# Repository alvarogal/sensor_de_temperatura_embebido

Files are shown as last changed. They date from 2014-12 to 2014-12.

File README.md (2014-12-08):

sensor_de_temperatura_embebido
==============================

Este proyecto integra el uso de un termopar con un sistema embebido usando linux, de tal forma que el usuario se pueda leer con un dipositivo conectado de forma inalámbrica al sistema, la temperatura medida en el termopar. Aquí se encuentran los recursos utilizados para lograr este objetivo.

Equipo de desarrollo.

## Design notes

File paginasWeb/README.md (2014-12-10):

Los archivos usados al final son:
server.js
index.html
guia1.html (grafica de la temperatura)
guias.html
tuto.html
inicio.html
medir.html (pagina que tienen el link para iniciar la grafica)
readTermo  (programa que usa server.js para leer el valor de temperatura en ese instante)
error (archivo donde se guarda un entero que lee con server.js e informa al usuario cuando el termopar se desconecta)
stylesheets (carpeta con los .css para el estilo de las paginas)
images (carpeta con las imagnes)

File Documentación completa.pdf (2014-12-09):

# SISTEMAS EMBEBIDOS DESARROLLO DEL PROYECTO

### Sebastián Corzo Gómez – scorzog@unal.edu.co José Logreira Ávila – jalogreiraa@unal.edu.co

## Stamp-Mini

Se eligió utilizar la tarjeta mini-stamp, diseñada por el ingeniero Camargo, que es una versión compacta de una tarjeta con mayores prestaciones. El diseño del PCB fue hecho en Kicad, y la lista de materiales fue elaborada por Camargo, incluyendo los códigos de las partes en Digikey. Los materiales fueron pedidos por Digikey.com, y las PCBs fueron elaboradas en PCBcart en China.

### Ensamble de la tarjeta:

Materiales y herramientas necesarias para el ensamble:

- Estación de soldadura: Pinzas de soldadura, Cautín con punta fina.
- Líquido Flux, para limpieza de superficies
- Alcohol isopropílico

Se inicia soldando los componentes pasivos, como los condensadores y las resistencias. Se limpia la PCB con alcohol isopropílico usando un cepillo. Una vez seca se deben estañar todos los pads de los componentes a soldar. Los circuitos integrados no se les debe aplicar mucho estaño a los pads, puesto que al poner el chip, no sería fácil posicionarlo pues los pads estarían abultados.

Se aplica un poco de Flux en los pads del componente a soldar. Con las pinzas para soldadura se coge el componente a soldar por las puntas metalizadas, y se ubica encima de los pads donde este debe ser soldado. El calor derretirá el estaño ya aplicado en los pads, y también quedará adherido a los extremos metalizados del componente. Cuando el componente haya entrado en contacto con el estaño de los pads en sus dos extremos, la pinza se puede retirar, y se verifica si el componente quedó fijado firmemente, o si está levantado. Usando las mismas pinzas de soldadura se pueden realizar reacomodaciones del componente. Es importante siempre usar Flux cuando se solde cada componente, pues limpia la superficie y ayuda a una mejor transferencia de calor.

Al soldar los chips (procesadores y memorias), se debe primero posicionar el IC tal que todas las patas queden alineadas con las pistas a las que van soldadas. Manteniendo fijo el chip, con el cautín de punta fina, se solda solo la pata de un extremo, y la pata del extremo opuesto, pasando ligeramente el cautín sobre la pata a soldar. Solo con estas dos patas soldadas, se verifica que todas las demás patas del IC continúen alineadas con las pistas del PCB. Si no lo están, pasando repetidamente el cautín por las patas soldadas se puede derretir el estaño y realinear el chip completo. Estando satisfechos con la alineación, se procede a soldar el resto de patas del IC, pasando rápidamente el cautín por cada pata individualmente, procurando que no haya estaño aderido a la punta del cautín.

Finalmente, se soldan las regletas laterales de la tarjeta. Cuando la tarjeta esté lista, se lava completamente con alcohol isopropílico, cepillandola con un cepillo de dientes. Se puede verificar con un multímetro que no haya continuidad de las lineas de alimentación y tierra, ni entre los pines de los chips. Esto teniendo en cuenta el esquemático del PCB.

### Comunicación con el exterior:

La tarjeta posee múltiples pines de comunicación. Los que se han de usar para la programación y la interfaz con el usuario son:

- USB DP (+) y DM(-): para realizar carga de programas pequeños a la memoria interna del procesador y probar el funcionamiento de la tarjeta.
- Serial Port Rx y Tx: Para la interacción entre el usuario y la tarjeta usando Minicom.

Para la comunicación usando los terminales USB, se usa un cable USB a miniUSB, al cual se le recorta el extremo del terminal miniUSB; a los 4 cables (+5V, GND, DP, DM), se les adapta una regleta hembra tal que se puedan conectar de a pares a la regleta macho de la tarjeta (+5V y GND juntos, y DP y DM juntos). Los terminales +5V y GND energizan toda la tarjeta.

Para la comunicación serial se requiere un IC que sirva de interfaz entre el protocolo USB y serial, pero usando niveles lógicos de 0V y 3.3V que son los que usa el procesador. Esta característica en el mercado se conoce como “USB to serial - TTL compatible”. En el mercado se consigue un pequeño PCB que tiene montado el conector USB, el IC PL2303hx, y 5 pines de salida, que son Rx, Tx, GND, +5V, +3.3V. Para comunicar la tarjeta con esta interfaz se usa un cable ribbon de 5 hilos, y en ambos extremos se le adapta regletas hembra para poderse conectar a los pines Tx Rx del PL2303hx, y a los pines Rx y Tx de la tarjeta.

### Prueba de funcionamiento:

Las instrucciones a continuación fueron entregadas por el Ing. Camargo para la prueba de la Ministamp. Se requiere de una memoria micro SD de 2GB o más, y el cable USB previamente fabricado. Previamente se requiere también instalar libusb, que se encuentra disponible en el gestor de software de Ubuntu, aunque la opción que nos funcionó correctamente fue descargar e instalar manualmente libusb desde el sitio oficial http://www.libusb.org/.

Descarga de Lua:
$ wget http://www.lua.org/ftp/lua-5.2.2.tar.gz
$ tar zxvf lua-5.2.2.tar.gz
$ cd lua-5.2.2
$ make linux
$ sudo make install
$ sudo cp /usr/local/lib/liblua.a /usr/lib/

Lua es un lenguaje compacto, interpretado, ligero y sencillo, y es uno de los que soporta el i.MX .

Crear las particiones necesarias en la SD, formatear la memoria SD y grabar el bootloader y el sistema de archivos:

Se necesitan dos particiones en la SD, la primera almacenará el boot-loader y la imágen del kernel; la segunda almacenará el sistema de archivos. Para los siguientes comandos se asume que la tarjeta es detectada como /dev/sdb (para conocer el dispositivo asignado a la tarjeta por Linux se debe insertar la tarjeta y ejecutar el comando $ dmesg)

Desmontar la partición y ejecutar fdisk:
$ sudo umount /dev/sdb*
$ sudo fdisk /dev/sdb

Borrar las particiones existentes: Dentro de fdisk se debe escribir "d" (delete a partition)

Command (m for help): d
Partition number (1-4):

En el campo "Partition number" se debe escribir el número de la partición a ser eliminada, el proceso se debe repetir hasta borrar todas las particiones existentes.

Crear una partición de 200MB : Dentro de fdisk se debe escribir "n" (add a new partition) . Seleccionar partición primaria: Escribir "p"

Command (m for help): n
Partition type:
p primary (0 primary, 0 extended, 4 free) e extended
Select (default p): p
Partition number (1-4, default 1): 1

Fijar el comienzo de la partición. Al mensaje:

First sector (2048-7626751, default 2048):

Se debe oprimir la tecla enter para asignar el valor por defecto. A lo que la aplicación responde:

Using default value 2048

Fijar el final de la partición. Al mensaje:
Last sector, +sectors or +size{K,M,G} (2048-7626751, default 7626751):

Ingresar +200M A lo que el sistema responde:

Partition 1 of type Linux and of size 200 MiB is set

Crear la segunda partición en el espacio sobrante en la SD : Dentro de fdisk se debe escribir "n" (add a new partition) . Seleccionar partición primaria: Escribir "p" . Asignar el número de la partición a "2"

Command (m for help): n
Partition type:
p primary (1 primary, 0 extended, 3 free) e extended
Select (default p): p
Partition number (1-4, default 2): 2

Fijar el comienzo de la partición: Dejar el valor por defecto Fijar el final de la partición: Dejar el valor por defecto

First sector (411648-7626751, default 411648):
Using default value 411648
Last sector, +sectors or +size{K,M,G} (411648-7626751, default 7626751):
Using default value 7626751
Partition 2 of type Linux and of size 3.5 GiB is set

Cambiar el tipo de la partición 1 a OnTrack DM6 (53) : Dentro de fdisk escribir "t" (change a partition's system id) . Escribir "53" . Este es el formato de partición que Freescale diseñó para el i.MX.

Command (m for help): t
Partition number (1-4): 1
Hex code (type L to list codes): 53
Changed system type of partition 1 to 53 (OnTrack DM6 Aux3)

Cambiar el tipo de la partición 2 a Linux (83) : Dentro de fdisk escribir "t" (change a partition's system id) . Escribir "83"

Command (m for help): t
Partition number (1-4): 2
Hex code (type L to list codes): 83

Al finalizar se debe tener la siguiente tabla de particiones, la cual se obtiene al ejecutar el comando "p" (print the partition table);

Device Boot | Start | End | Blocks Id System
/dev/sdb1 | 2048 | 411647 | 204800 53 OnTrack DM6 Aux3
/dev/sdb2 | 411648 | 7626751 | 3607552 83 Linux

Una vez finalizada la creación de las particiones se deben guardar los cambios en la tabla de particiones de la SD, para esto debe ejecutar el comando "w" (write table to disk and exit)

Command (m for help): w
The partition table has been altered!

Calling ioctl() to re-read partition table. Syncing disks.

Formatear la segunda partición como ext3:

$ sudo mkfs.ext3 /dev/sdb2

Almacenar el boot-loader y la imágen del kernel a la SD: El bootloader y la imágen se encuentran en la carpeta Factory_Test/basic/files.

$ sudo dd if=sd_mmc_bootstream.raw of=/dev/sdb1
$ sudo umount /dev/sdb*

Grabar el sistema de archivos a la segunda partición: El .tar.bz2 se encuentra en la carpeta files.

$ sudo tar -jxvf buildroot_fs.tar.bz2 -C /media/disk/

Cambiar los OTPs para permitir la inicialización por la SD (se realiza solo una vez): Por defecto el iMX233 no permite inicializar desde la SD, para habilitar esta opción es necesario cambiar el valor del registro interno OCOTP.ROM0, esto se realiza una única vez.

Compilación de las herramientas necesarias para la modificación del registro OCOTP.ROM0 Descomprimir y compilar el código fuente: en la carpeta basic:

$ cd Factory_Test
$ ./build

Al finalizar el proceso sin errores deben existir dos nuevos ejecutables en /usr/local/bin: hwstub_shell sbloader

Cargar la aplicación blink: (alimentar y conectar el cable USB a la stamp): Para asegurarse que la tarjeta es reconocida al conectarla, se ejecuta el comando $ lsusb.

load_blink

El LED D3 (esquina superior derecha) parpadeará, lo que indica que la placa se encuentra bien soldada y está funcionando de forma adecuada .

Para programar los registros que permiten arrancar desde la SD debe ejecutar el script

burn_OTP

Y con esto ya puede arrancar con la SD que creó anteriormente.

Se conecta el dispositivo USB a serial, usando el cable ribbon, a los pines Rx y Tx de la tarjeta, alimentandola también con los pines de +5V y GND. Se abre una consola de Minicom donde abre las opciones de configuración del puerto:

$ sudo minicom -s

En la pestaña serial port setup se configura el puerto del dispositivo a usar (en nuestro caso: /dev/ttyUSB0), se establece la rata de baudios y los bits de paridad y de inicio como 115200 8N1. No se habilita el flujo de control de hardware ni de software. Se guardan los cambios y se entra en la consola del puerto. Apenas se energiza la tarjeta, en la consola se muestran los comandos iniciales del boot del procesador, y comienza la carga del sistema operativo. Cuando el sistema termina de cargar, el SoC debe pedir el login: root, y el password: root. Al llegar a este paso, todo el sistema cargó correctamente y ya se puede empezar a hacer uso del OS cargado en la tarjeta.

NOTA: El bootloader, el kernel y el sistema de archivos cargados hasta ahora son todos imágenes precompiladas por el Ing. Camargo, que se usan únicamente para probar el funcionamiento inicial de la tarjeta. A continuación se describe cómo compilar desde ceros la imagen del kernel y el sistema de archivos.

### Compilando la imagen del Sistema de archivos

Parte del material del curso es el archivo comprimido buildroot-2013.08.1. Este contiene un programa llamado Buildroot. Es una herramienta que simplifica y automatiza el proceso de creación de un sistema Linux completo para un sistema embebido, usando la compilación cruzada. Para construir el sistema Linux, Buildroot puede generar un set de herramientas de crosscompilación, un sistema de archivos raíz, una imágen del núcleo Linux y un gestor de arranque (bootloader) para la mini-stamp.

Buildroot se puede usar para cualquiera de las tareas anteriormente descritas, en cualquier combinación que se quiera. Soporta múltiples procesadores y viene con múltiples configuraciones preformadas para tarjetas específicas.

En el directorio raíz buildroot-2013.08.1 se encuentra un Makefile con el cual se realizan todas las acciones necesarias a usar con Buildroot. Al ejecutar:

$ make menuconfig

Se abre una interfaz gráfica en donde se encuentran jerarquizadas todas las opciones de configuración de Buildroot: se puede elegir que clase de sistema de archivos crear, que versión de kernel, que opciones de boot, que paquetes y aplicaciones se desean incluir en el sistema de archivos, que herramientas de desarrollo se desean incluir, etc. Por defecto ya viene un archivo de configuración cargado con las opciones básicas para realizar aplicaciones sencillas con la ministamp. Este archivo se llama .config y se encuentra en el directorio raíz de Buildroot. Si se realizan cambios en la interfaz de configuración, y se guardan los cambios, este archivo se modifica.

Por ahora, la configuración que viene por defecto es casi suficiente para nuestro propósito por lo que solo es necesario modificar un par de parámetros: en menú System Configuratio, se modifica el System banner: “Welcome to buildroot: Sebastián y Jose”, y el parámetro Port to run a getty (logging prompt) on: “ttyAM0”, que es el puerto serial del SoC a través del cual se va a transmitir a Minicom la consola de Buildroot.

Correr Buildroot con la configuración por defecto creará un sistema de archivos básico y toda la cadena de herramientas del cross-compilador. No creará un bootloader, ni una imágen del kernel

Linux.

Para correr Buildroot, nos ubicamos en el directorio raíz de buildroot, y se ejecuta $ make. Comienza un proceso de descarga de internet de todos los paquetes necesarios, que los va guardando como comprimidos en la carpeta buildroot-2013.08.1/dl. Luego empieza a compilarlos usando el cross-compilador seleccionado para el i.MX. Este es un proceso que puede tardar al rededor de 2 horas.

Al llegar a la compilación del paquete llamado openocd, muestra un error por un Warning, y no permite continuar con la compilación. Este error es debido a que en el Makefile de este paquete, los warnings están definidos para que los tome como errores. Por esto, algunos warnings que no afectan el funcionamiento del sistema son tomados como errores. Para solucionarlo, nos dirigimos hasta donde se encuentra el Makefile en ejecución, que se encuentra en la ruta: buildroot-2013.08.1/output/build/openocd-0.7.0/src/target, y se abre el Makefile con gedit. Se busca el flag -Werror, que está escrito dos veces en todo el archivo. Se borra y se guardan los cambios.

Nuevamente se regresa al directorio raíz de buildroot y se vuelve a correr $ make. Esta vez la compilación continúa sin errores hasta que acaba todas las tareas. El resultado final es que en el directorio buildroot-2013.08.1/output/images se encuentra la imágen del sistema de archivos creada, comprimida. Teniendo esta imágen ya creada, se descomprime en la segunda partición de la SD.

### Compilando la imagen del Kernel de Linux:

Parte del material de clase son dos archivos comprimidos llamados:

- linux-2.6.35.3.tar.bz2: Contiene todo el código fuente del núcleo Linux. Además, también contiene un programa con una interfaz gráfica basada en la librería curses (la misma usada para el programa buildroot) donde se encuentran múltiples opciones de configuración del kernel.
- Imx-bootlets-src-10.05.02.tar.bz2: Son herrmientas para copiar la imagen de linux (creada en la carpeta anterior) a la SD, junto con un conjunto de configuraciones de registros internos del procesador i.MX, necesarios para que este pueda inicializar reguladores de tensión, memorias externas y buses de comunicación.

Estos se descomprimen en un mismo directorio.

### Modificación de la variable PATH:

Un primer paso en modificar la variable de entorno PATH, añadiendole la ruta donde se encuentra el cross-compilador que fue creado usando buildroot. Esto se realiza modificando el archivo .bashrc que se encuentra en el folder del usuario (/home/jose en nuestro caso):

### $ cd /home/jose $ gedit .bashrc

Al final del archivo se añade la linea de comando:

export PATH=$PATH:/home/jose/Documents/EMBEDDED_SYSTEMS/buildroot-2013.08.1/output/host/ usr/bin/

Esto modifica la variable PATH añadiendole una nueva ruta de búsqueda de ejecutables. La ruta especificada es donde se encuentra el cross-compilador.

### Creación de la imagen de Linux:

Dentro de la carpeta linux-2.6.35.3 hay un Makefile que será usado para compilar todo el núcleo Linux, usando el cross-compilador generado en la carpeta buildroot-2013.08.1.

Para editar las opciones de configuración del kernel, se abre la interfaz gráfica parecida a la existente en buildroot-2013.08.1, la cual permite listar y seleccionar las múltiples configuraciones. Para esto se ejecuta en el directorio raíz de linux-2.6.35.3:

$ make ARCH=arm CROSS_COMPILE=arm-linux- menuconfig

donde ARCH=arm especifica que se va a compilar para la arquitectura ARM, y CROSS_COMPILE = arm-linux- especifica el cross-compilador que se va a usar. Finalmente, se especifica la directríz a ejecutar: menuconfig.

Al ejecutar este comando, se presenta un error de un enlace roto a un archivo. En la carpeta buildroot-2013.08.1/output/host/usr/bin/ existen múltiples archivos que son enlaces a otros archivos ubicados en esa misma carpeta. El enlace roto se presenta en este archivo: arm-linuxld.real, que apunta a arm-buildroot-linux-uclibcgnueabi-ld.real. Este problema se soluciona creando manualmente el enlace, así:

$ ln -s arm-buildroot-linux-uclibcgnueabi-ld.real arm-linux-ld.real

donde la opción “-s” crea un enlace simbólico entre ambos archivos.

Al volver a correr el comando make (…) se abre la ventana de la interfaz gráfica que muestra las opciones de configuración del kernel.

Al correr el siguiente comando, se genera la imágen del kernel de linux:

$ make ARCH=arm CROSS_COMPILE=arm-linux-

Esta ejecución se demora de 10 a 15 minutos. La imagen final del Kernel Linux la crea en la carpeta linux-2.6.35.3/arch/arm/boot, y tiene como nombre zImage. Éste es el Sistema Operativo propiamente dicho, el cual se debe grabar en la primera partición de la SD, usando las herramientas ubicadas en la carpeta Imx-bootlets-src-10.05.02.

### Pasar la imagen del Kernel a la SD:

La carpeta Imx-bootlets-src-10.05.02 con la configuración necesaria para el I.MX es proporcionada por Freescale, y contiene la configuración de boot del procesador, donde inicializa los buses de comunicación con las memorias, los reguladores internos de voltaje y registros de configuración.

En el directorio raíz de la carpeta hay un Makefile, el cual se debe correr para pasar la imagen del Kernel a la tarjeta SD. Se debe asegurar que la tarjeta micro SD sea leída como “sdb”, puesto que así está definida la ruta en el Makefile. Si se usa un adaptador microSD a USB, el sistema leerá la SD como un dispositivo de nombre “p”, por lo que se debe modificar esta ruta a /dev/p1.

Para correr el Makefile, se ejecuta el comando siguiente:

$ make ARCH=mx23 CROSS_COMPILE=arm-linux-

Este comando arroja error en la compilación pues no encuentra el comando “elftosb2”, el cual es el programa encargado de convertir el formato de archivos elf (Executable & Linkable File) al formato sb, que es el que reconoce el procesador.

Este programa nos lo envió el Ing. Camargo. Es un archivo binario que se debe copiar en la carpeta /usr/bin, y se le deben cambiar los permisos de ejecución:

$ sudo chmod +x /usr/bin/elftosb2

Así, al volver a correr el Makefile, este realiza todos los procesos sin errores, y la imágen del kernel ya queda pasada sin problemas a la SD.

Para comprobar que todo haya salido bien, se inserta la SD en la mini-stamp, se conecta su puerto serial a minicom y se energiza la tarjeta. Primero debe mostrar información de inicialización de todos los registros internos del IMX, y luego empear a cargar el sistema operativo. El mensaje final que aparece es "Welcome to Buildroo2", junto con una petición de login: user: root, password: qwerty. Al iniciar la sesión, ya podemos navegar entre las carpetas del sistema de archivos y asegurarnos que todas contengan los archivos y carpetas necesarias para el funcionamiento del sistema de archivos.

### Realizando pruebas con Drivers:

Los drivers son archivos que contenen el código fuente de la configuración de distintos periférios y demás disposotivos externos. Estos realizan las tareas de comunicación entre el OS y el Hardware que se quiere usar. A continuación se describe el uso de un Driver.

En la carpeta Examples/imx233/drivers/blink (incluida en el material del curso) se encuentra un ejemplo de un driver. Esta carpeta solo contiene 2 archivos: blink.c y Makefile. El driver es el blink.c. En este archivo se encuentran definidos los puertos de I/O que va a usar el driver, la configuración de funciones que va a ejecutar, entre otras cosas. Este driver ejecuta una rutina de encendido y apagado 5 veces de un LED, cada vez que recibe un comando de escritura.

Para compilar el driver se usa el Makefile. Pero se debe asegurar que el path a la carpeta raíz de la versión compilada de linux sea el correcto. Además, se debe asegurar que esté bien escrito los nombres de los compiladores, y el nombre del archivo objeto a compilar. En nuestro caso:

CC = arm-linux-gcc
KERNEL_SRC = /home/jose/Documents/EMBEDDED_SYSTEMS/linux-2.6.35.3
CROSS_COMPILE = arm-linux-

obj-m += blinker.o

Una vez asegurado esto, desde la carpeta que contiene el Makefile sólo se ejecuta:

$ make

Este proceso arroja un archivo de extensión .ko, que es el driver compilado para la arquitectura deseada. Este archivo se debe copiar en cualquier parte de la SD (nosotros creamos en el directorio raíz: /drivers), y para ejecutarlo, desde la terminal de la mini-stamp se ejecuta el comando:

$ insmod blinker.ko

Todos los drivers deben tener una función de inicializar (init) y una función de cerrar (exit), las cuales definen algún tipo de configuración del driver, como los pines de I/O que se quieren usar. Al ejecutar el comando anterior, se inserta el módulo en el kernel de linux, y se llama a la función init. En el archivo /proc/devices se crea un registro de todos los drivers presentes, en donde debe aparecer el actualmente creado, llamado "blink". También le asigna un número de identificación. Esto se visualiza al ejecutar:

$ cd /proc
$ more devices

El número asignado es el 252 en nuestro caso. Para comenzar a usar el driver, se debe crear manualmente el archivo que va a manejar el puerto, así:

$ mknod /dev/blink c 252 0

La "c" quiere decir que la comunicación del driver es de tipo caracter, es decir, que se envían tramas de 8 bits al ejecutar la función de escritura. Para asegurarse que se haya creado correctamente, se pueden listar los dispositivos actualmente presentes en el SoC:

$ ls /dev

Allí debe aparecer creado el blink.
Para comunicarnos con el periférico, una de sus funciones es escribir. Esto se puede hacer así:

$ echo A> /dev/blink

Al recibir el caracter A, el driver ejecuta la rutina de encendido y apagado del LED.

### Programando el ADC del SAM3N:

Para poder usar el SAM3N, este requiere de un sistema operativo que lo controle. Se llama ChibiOS, que es un OS muy liviano y orientado a la programación de aplicaciones en tiempo real. Permite crear hilos de procesos paralelamente, y manejar todos los periféricos del SAM3N.

La aplicación que se desee implementar con el SAM3N se escribe en código C, y usando la cadena de herramientas de compilación para el SAM, se genera un archivo binario ch.bin, que es el que contiene tanto el OS que va a controlar el procesador, como el código de la aplicación que se desea correr.

Para pasar este archivo a la memoria del SAM, primero se copia en alguna parte de la SD, y luego se usa la aplicación “openocd” para enviar vía puerto serial, el ch.bin desde la memoria SD, a través del iMX, hasta la memoria del SAM. La aplicación Openocd fue incluida dentro del sistema de archivos cuando fue creado.

Para el caso del uso del ADC, el ejemplo se encuentra en /ChibiOS_mini/demos/ARMCM3-SAM3N-EK/main.c; en esa carpeta también se encuentra el Makefile, así como todos los demás archivos y librerías provistas por Atmel para usar las múltiples funciones preprogramadas. Para compilar el código del ADC junto con el OS: $ make. Esto crea el ch.bin, que se pasa a la SD, junto con múltiples archivos de configuración del SAM, también presentes en la carpeta del main.c

Desde la terminal de la Mini-stamp, en la ubicación del ch.bin:

$ openocd -f stamp_mini_sam3n.cfg

Para crear el nodo de comunicación entre el SAM y el iMX, que va a ser un puerto serial:

$ mknod /dev/ttySP1 c 242 0

El “c” significa: comunicación tipo char: envío de datos por carácter, no por bloques.
El puerto serial está por defecto configurado para una velocidad de transmisión de 38400 baudios, pero el ejemplo del ADC transmite a 115200 baudios. Para cambiar esto:

$ stty -F /dev/ttySP1 115200

Ahora sí, se puede ver lo que está recibiendo el puerto:

$ cat /dev/ttySP1

El proceso se corta con ctrl + C.

### Usando Interrupciones en los Drivers:

Otro ejemplo es dado para comprender el uso de interrupciones en los drivers de dispositivo. En la carpeta Examples/imx233/drivers se encuentra el ejemplo IRQ. En el driver de este ejemplo se encuentra definida la interrupción a implementar, que es detectada cuando en el pin definido hay un cambio de nivel lógico.

La estructura de este ejemplo es: ......

La estructura de la interrupción es: ....

La compilación de este driver es muy parecida a la del ejemplo del blinker: se verifican los paths del Makefile, y los compiladores a usar. Se ejecuta el comando make, y el archivo .ko resultante se pasa a la tarjeta. Desde allí se inserta al kernel de Linux (con insmod), y se crea el nodo de comunicación (mknod). El driver ahora tiene la funcionalidad de producir interrupciones en el sistema.

## Montaje de la Red Inlámbrica

### COMANDOS:

$ ifconfig: muestra el estado de las interfaces de red actualmente activas
$ iwconfig: similar a ifconfig, pero solo para redes inalámbricas. No sale la misma info
$ ping <IP_dir> realiza test de comunicación

Se eligió usar la tarjeta de red USB Minicasadora de 3bumen, con chip RT3070 de Ralink.

Al conectar la minicazadora, en $ifconfig debería salir la wlan. No hemos hecho la prueba

### PROGRAMAS:

Servidor DHCPD: Dynamic Host Configuration Protocol Daemon
DHCPD: DHCO daemon: un daemon es un programa que corre en segundo plano, sin interfz directa con el usuario. DHCPD es el programa que corre en segundo plano en un servidor, que gestiona la asignación de IP dinámicamente.

The DHCP server then offers the "lease" of an IP address to the client, which the client is free to request or ignore. If the client requests it and the server acknowledges it, then the client is permitted to use that IP address for the "lease time" specified by the server. At some point before the lease expires, the client must re-request the same IP address if it wishes to continue to use it. Issued IP addresses are tracked by dhcpd through a record in the dhcpd.leases file

dhcpd.conf: the network administrator allocates address pools in each subnet and enters them into the dhcpd.conf(5) file.

On startup, dhcpd reads the dhcpd.conf file and stores a list of available addresses on each subnet in memory. When a client requests an address using the DHCP protocol, dhcpd allocates an address for it. Each client is assigned a lease, which expires after an amount of time chosen by the administrator (by default, one day). Before leases expire, the clients to which leases are assigned are expected to renew them in order to continue to use the addresses. Once a lease has expired, the client to which that lease was assigned is no longer permitted to use the leased IP address.

Whenever changes are made to the dhcpd.conf file, dhcpd must be restarted. To restart dhcpd, send a SIGTERM (signal 15) to the process ID contained in /var/run/dhcpd.pid, and then re-invoke dhcpd. Because the DHCP server database is not as lightweight as a BOOTP database, dhcpd does not automatically restart itself when it sees a change to the dhcpd.conf file.

biblio:
http://www.linuxcommand.org/man_pages/dhcpd8.html
http://en.wikipedia.org/wiki/Lease

Hostapd is a user space daemon (http://en.wikipedia.org/wiki/Daemon_(computing)) for wireless access point and authentication servers.
hostapd is configured using a text file that lists all the configuration parameters.
The current version supports Linux (Host AP, madwifi, mac80211-based drivers) and FreeBSD (net80211).
All new mac80211 based drivers that implement AP (Access Points) functionality are supported with hostapd's nl80211 (http://wireless.kernel.org/en/developers/Documentation/nl80211) driver.
nl80211 is the new 802.11 netlink interface public header. Together with cfg80211 (http://wireless.kernel.org/en/developers/Documentation/cfg80211) it is intended to replace Wireless-Extensions. nl80211 and cfg80211 (http://wireless.kernel.org/en/developers/Documentation/cfg80211) are still under development.
You will also want to do a survey of your area to find the channel that has the fewest other APs on it. When choosing which channel to use, it is important to remember that the channels overlap with any channels that are within 20MHz.

Biblio:
http://hostap.epitest.fi/hostapd/
http://wireless.kernel.org/en/users/Documentation/hostapd

COPIAR ARCHIVOS A LA MINI-STAMP POR LA RED:

SCP significa Secure CoPy es una pata más de SSH, que permite transferir archivos o carpetas entre computadores. La sintaxis es bien simple:

$ scp archivo usuario@servidor.com:ruta

Y para copiar a la inversa, desde el computador remoto al tuyo, simplemente tienes que invertir el orden de los elementos:

$ scp usuario@servidor.com:ruta/archivo ruta_local

O sea por ejemplo, si quisiéramos mandar algo al servidor:

$ scp hola.txt tomas@bootlog.cl:/www/sitio

Mandaría el archivo hola.txt y lo dejaría en la carpeta /www/sitio en el servidor bootlog.cl. También puedes mandar carpetas completas (con ):

$ scp -r viajealsur/ tomas@bootlog.cl:/www/sitio/fotos

Así mandaría la carpeta /viajealsur completa a /www/sitio/fotos. Ahora, el mismo proceso a la inversa sería:

$ scp -r tomas@bootlog.cl:/www/sitio/fotos/viajealsur ~

Esto copiaría la carpeta viajealsur/ del servidor a mi carpeta /home.

http://pintucoperu.wordpress.com/2007/11/27/como-usar-scp-el-complemento-de-ssh-paratransmitir-archivos-y-carpetas/ (http://pintucoperu.wordpress.com/2007/11/27/como-usar-scp-el-complemento-de-ssh-para-transmitir-archivos-y-carpetas/)

En el caso de la ministamp:
$ scp <ruta_al_archivo> root@192.168.50.1:<ruta_de_destino>

### AHORA SÍ EL MONTAJE DE LA RED:

Inicialmente se siguieron las instrucciones de los archivos .ps enviados por Camargo: network.ps y rt3070_1.ps

Darle soporte de Drivers al Kernel linux: El chip es de Ralink. Es el rt3070l. Desde la carpeta de linux, se ejecuta la interfaz de menuconfig:

$ make menuconfig
o
$ make ARCH=arm CROSS_COMPILE=arm-linux- menuconfig
-->No sé cual es la diferencia entre los dos

Se le da soporte a los chips de Ralink como dice el apéndice B del documento. Se vuelve a compilar la imagen del kernel, que queda ubicada en <linux>/arch/arm/boot. Usando iMXbootlets se pasa la imágen a la SD.

Desde el sistema de archivos de la SD (mini-stamp), se deben modificar algunos archivos para configurar la red, según la guia networks.ps:

- Configurar dhcpd: en el archivo etc/dhcp/dhcpd.conf , se cambian las direcciones IP según la guia.
- Se crea el archivo que no existía etc/default/isc-dhcp-server , con la linea INTERFACES=”wlan0”
- Se configura hostapd: el archivo /etc/hostapd/hostapd.conf se modifica, se le da nombre a la red ssid=osciloscope. Algunas de las líneas de opciones de hostapd.conf que sugería la guia se comentaron, según les había funcionado a otro grupo.
- Configurar red local del servidor: /etc/network/interfaces . Se debe poner una IP fija para el servidor. Algunas de las líneas de código que sugiere la guia se cambiaron, según Camargo indicó en archivos pasados por correo.

Adicionlmente, como soporte para manejar la tarjeta de red, al parecer en la carpeta /lib/firmware no están los archivos necesarios para manejar la tarjeta, por lo que Camargo nos pasó unos archivos de firmware .bin adicionales que se metieron en esta carpeta.

Como a varios no les funcionaba la red, Camargo comparó dos sistemas de archivos: el de la ministamp de él, y el de la del grupo de Santiago. Luego de eso, nos envió archivos que estaban distintos para añadir a nuestra SD:

- En init.d: se adicionaron los 2 archivos que envió.
- En Network: se modificó interfaces, cambiando las opciones que decía la guia.
- Se agregó la carpeta etc/wireless, que no existía
- inittab no tuvo cambios
- wpa_suplicant.conf sí cambió: todos los parámetros de Network se agregaron.
- En /lib/firmware se agregaron todos los .bin que envió.
- En /lib se añadieron todos los demás archivos que envió
- en /root se metieron los archivos y carpetas mandados

Adicionalmente, Santiago envió unos pasos para conectarse de manera manual a la tarjeta, descritos a continuación. Sin embargo, la mayoría de los pasos ya han sido realizados. Lo que cambia es recompilar el sistema de archivos para incluir udev: que es el gestor de dispositivos de manera dinámica. También es nuevo el crear el archivo S51hostapd.

Configurar la red Wifi

Es necesario que se seleccione el udev desde buildroot. udev es un administrador de dispositivos que asigna de manera dinámica los drivers de dispositivos y evita que uno tenga que hacer la configuración manualmente.
ir a /buildroot-2013.08.1.
make clean
make menuconfig
System Configuration --> /dev management --> Dynamic using udev
make

NOTA IMPORTANTE: como udev administra dinámicamente los drivers, sólo crea los archivos cuando los necesita. Por lo tanto, el sistema de archivos que incluya udev tiene la carpeta /dev prácticamente vacía. Hay que extrar en la microSD el sistema de archivos primero sin udev (de manera que se carguen los drivers que tienen soporte) y después sí extraer el sistema de archivos con udev.
Agregar carpetas y archivos faltantes. Copiar la carpeta filesystem_mini_network_client dentro de la microSD.
revisar y configurar los siguientes archivos:
/etc/default
isc-dhcp-server
INTERFACES="wlan0"
/etc/hostapd
hostapd.conf

interface=wlan0
driver=nl80211
ssid=NOMBRE_RED
channel=1
hw_mode=g
auth_algs=1
#wpa=3

#wpa_passphrase=siebot_2013 #wpa_key_mgmt=WPA-PSK

#wpa_pairwise=TKIP CCMP

rsn_pairwise=CCMP
/etc/network
interfaces

# Configure Loopback

auto lo
iface lo inet loopback

auto wlan0
iface wlan0 inet static
address 192.168.50.1
netmask 255.255.255.0
gateway 192.168.50.1
wireless_essid NOMBRE_RED
wpa-ssid NOMBRE_RED
wpa-psk 1011215410
wpa-conf /etc/wpa_supplicant.conf
/etc/dhcp
dhcpd.conf

subnet 192.168.50.0 netmask 255.255.255.0 {
range 192.168.50.5 192.168.50.20;
option domain-name-servers 192.168.50.1, 192.168.50.1;

option routers 192.168.50.1; }
/etc/
wpa_supplicant.conf

ctrl_interface=/var/run/wpa_supplicant #ap_scan=1

network={
ssid="NOMBRE_RED"
scan_ssid=1
key_mgmt=WPA-PSK
psk="1011215410"
proto=RSN WPA
pairwise=CCMP TKIP
group=CCMP TKIP
}
/_
make_snd
Eliminar todos los sudo's que haya. La stamp no identifica ese comando a menos que en el sistema de archivos le hayan dado soporte.
Los valores en azul dependerán del nombre y la dirección que cada grupo quiera para su tarjeta. Crear script de inicio
ir a /etc/init.d
crear un archivo llamado S51hostapd con la siguiente línea
/usr/sbin/hostapd /etc/hostapd/hostapd.conf &

Este script se ejecuta al iniciar el sistema y configura la red como access point.

Muchachos, una aclaración. La carpeta filesystem_mini_network_client en donde están los archivos que hay que modificar NO la crea el sistema. Esa carpeta la envió Camargo. En caso de que les falte algún archivo o carpeta lo pueden crear como texto plano y poner lo que dice ahí.

Otra aclaración.

es necesario escribir la siguiente línea en la consola del computador.

apt-get install dhcp3- server dhcp3-client

Esto va a permitir que la red que creamos asigne direcciones de manera dinámica. Sin embargo, esto no está funcionando bien entonces hay que hacerlo, por ahora, de manera manual. Para ello hay que hacer lo siguiente:

Una vez se conecten a la tarjeta desde, por ejemplo, el computador deben editar las conexiones inalámbricas (en la barra de arriba donde salen las conexiones de red --> Edit connections --> Wireless --> Seleccionan su red (NOMBRE_RED) --> Edit). Buscan la pestaña IPv4 Settings y en Method seleccionan Manual. Agregan una dirección y ponen lo siguiente.

Addresses
Address | Netmask | Gateway
192.168.50.2 192.0.0.0 | 192.168.50.1

DNS servers: 192.168.50.1

El color en rojo es la dirección de su computador en el servidor de la tarjeta.

Eso siempre se demora un poquito en conectar.

Para ver (desde la tarjeta) que la red sí está habilitada deben escribir ifconfig y debería salir wlan0.

con el comando ssh root@192.168.50.1 desde la consola del computador se pueden conectar a la tarjeta (controlar la tarjeta desde el pc). Es posible que en este paso les salga un mensaje de "error" en donde dice que no es seguro conectarse. En este caso hay que ir a buildroot y poner una contraseña al sistema, esa es la contraseña para acceder a la tarjeta. NO es necesario hacer make clean en buildroot para poner la contraseña.

El make_snd se dejó en la carpeta raíz de la SD.

Luego Camargo envió el siguiente correo:

Hola muchachos

Para que puedan correr bien el ejemplo del blink en la tarjeta no es necesario usar boa. boa es un servidor web que utilizamos para colocar páginas web, pero el ejemplo del blibnk que les moestré crea su propio servidor en el puerto 8888

Lo que deben hacer es correr el programa con node:

node blink.js

al ejecutar ese comando se crea el servidor en el puerto 8888

para verificar que esté funcionando bien deben ingresar a la siguiente dirección

http://192.168.50.1:8888
(o la dirección que le pusieron a su tarjeta)

Ya pueden probar la configuración del http, el problema que tenían era elmismo de la falta de asignación de IP, como ya tienen un IP asignado pueden ejecutar:

dhcpd -cf /etc/dhcp/dhcpd.conf wlan0 &

y ahi seguramente ya les da una dirección IP sin tener que ponerla a mano

Y Ricardo, nos envió el siguiente correo:

Buenas noches, hoy estuvimos mirando lo del javascript y relaizamos los siguientes cambios para que el servidor realizara todas las configuraciones de red de forma automática en cualquier dispositivo que se desee conectar para no tener que hacerlo cada vez de forma manual. Lo que hicimos fue lo siguiente:
En la carpeta /etc/init.d/
Modificar el archivo S51HOSTAPD
de la siguiente forma:

/usr/sbin/hostapd /etc/hostapd/hostapd.conf & %%% ESTA ES LA QUE YA ESTÁ, NO REPETIRLA!!

touch /var/lib/dhcp/dhcpd.leases %%% PARA QUE DEJARA CORRER EL DHCPD.CONF FUE NECESARIO CREAR ESTE ARCHIVO

dhcpd -cf /etc/dhcpd.conf wlan0 & %%%VUELVE A HABILITAR LA RED YA QUE CON EL COMANDO

ANTERIOR SE DESMONTA

mkdir /var/log/boa %%% CREA EL BOA PARA PODER ACCEDER A LA TARJETA DESDE EL NAVEGADOR

Con esto ya se pueden conectar directamente desde cualquier computhttp://www.google.com/search?q=192%3A168%3A50%3A1&ie=utf-8&oe=utf-8&client=ubuntu&channel=fsador o celular.
Cualquier cosa me cuentan.

Para crear el AP se ejecuta

$ hostapd /etc/hostapd/hostapd.conf

El Hostapd funciona y crea el AP, pero dhcpd no funciona aún. Conectandose con IP fija a la tarjeta y cargando el ejemplo del blink, se puede correr el ejemplo del blink

$ cd /var/www/
$ node blink.js

El problema que muestra el dhcpd al correr $ dhcpd -cf /etc/dhcp/dhcpd.conf wlan0 &, es: “Can't open lease database /var/lib/dhcp/dhcpd.leases: No such file or directory”.

Según la documentación:
Dhcpd can be made to use an alternate configuration file with the -cf flag, or an alternate lease file with the -lf flag. Because of the importance of using the same lease database at all times when running dhcpd in production, these options should be used only for testing lease files or database files in a non-production environment.

Se intentó agregar la linea $ dhcpd -lf /var/lib/dhcp/dhcpd.leases &. al archivo S51hostapd.
No funcionó.

Al buscar el archivo desde la consola de la mini-stamp, NO aparece el archivo dhcpd.leases.... no sabemos como hacerlo aparecer. Al parecer el sistema lo borra al reiniciarse.

Funcionó así:
Se eliminan las líneas del S51hostapd, dejando solo las iniciales:

#touch /var/lib/dhcp/dhcpd.leases

#dhcpd -cf /etc/dhcp/dhcpd.conf wlan0 &

#dhcpd -lf /var/lib/dhcp/dhcpd.leases &

#mkdir /var/log/boa

Se movio el .leases a var/lib
Se creó un script (.sh) que hacía lo siguiente: #!/bin/bash
hostapd /etc/hostapd/hostapd.conf &
sleep 5
dhcpd -lf /var/lib/dhcpd.leases &
sleep 5
cp /var/lib/dhcpd.leases /var/lib/dhcp/
dhcpd -cf /etc/dhcp/dhcpd.conf wlan0 &

Arranca el hostapd; espera 5s para que arranque; luego cambia la ruta del archivo .leases e inicializa el archivo; espera 5 segundos a que haga esto; copia el archivo .leases a la carpeta /var/lib/dhcp, para que al ejecutar la siguiente instrucción, se encuentre el archivo. Esto se hace para que al iniciar el sistema, cuando borra el .leases, el script lo vuelva a crear e inicializar.

El script se guardó en el root de la SD, y se ejecuta así:

$ cd /;
$ ./network.sh

# PROYECTO

### OSCILOSCOPIO DIGITAL

### DESCRIPCIÓN DEL PROYECTO

El objetivo es crear un dispositivo con el cual el estudio de los circuitos y las señales eléctricas sea más intuitivo y natural. Este dispositivo funcionará como voltímetro digital u osciloscopio. Será usado en colegios del distrito para la enseñanza básica en física. Este deberá ser económico y presentar un diseño simple y robusto, para estudiantes de colegio de múltiples edades.

Se quiere usar la plataforma embebida | MINI-STAMP (http://embedded-corzo-logreira.wikispaces.com/MINI-STAMP) | como sistema de adquisición de señales
eléctricas, y envío de las mismas, por medio de una red LAN, a un dispositivo móvil para su visualización.

### CARACTERISTICAS:

- Sensado de señales eléctricas de tensión entre -5 y 5V
- Dos canales de medición
- Uso de sondas de tensión sin atenuación

### 2. PROYECTOS SIMILARES

### 2.1 LabQuest 2

Un ejemplo de plataforma comercial es la llamada LabQuest 2, que es un pequeño sistema capáz de integrar la medición de múltiples variables, visualizarlas en un entorno agradable, almacenarlas y procesarlas para realizar análisis. La plataforma soporta múltiples sensores estándar, como: temperatura, sonido, luz, posición (por ultrasoido), etc. http://www.vernier.com/products/interfaces/labq2/

Esta plataforma permite almacenamiento y procesamiento de datos, así como conexión a internet y envío de información. El LabQuest 2 cuesta USD 329.
2.2 BBB - High speed data acquisition and web-based UI (http://www.element14.com/community/community/knode/single-board_computers/next-gen_beaglebone/blog/2013/08/04/bbb--high-speed-data-acquisition-and-web-based-ui)

http://www.element14.com/community/community/knode/single-board_computers/nextgen_beaglebone/blog/2013/08/04/bbb--high-speed-data-acquisition-and-web-based-ui (http://www.element14.com/community/community/knode/single-board_computers/next-gen_beaglebone/blog/2013/08/04/bbb--high-speed-data-acquisition-and-web-based-ui)

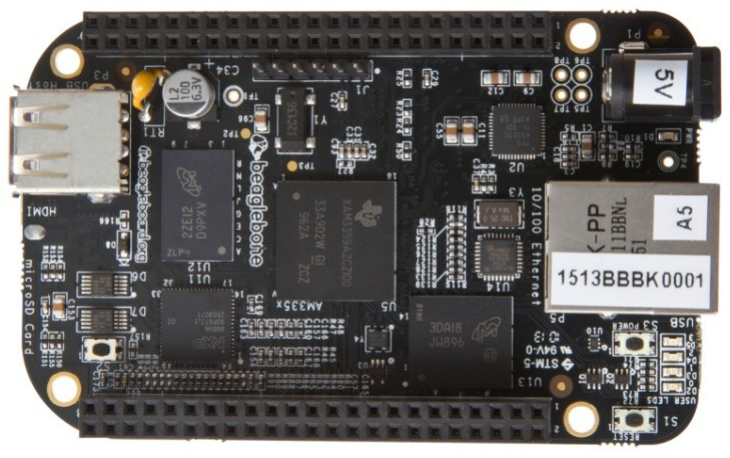
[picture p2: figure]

Usando la plataforma Beagle-Bone Black, realizan un sistema de transmisión de datos vía WiFi de alta velocidad que permite sensar una señal con un ADC de alta frecuencia de conversión, y enviar los datos a un dispositivo móvil en el cual son visualizados.

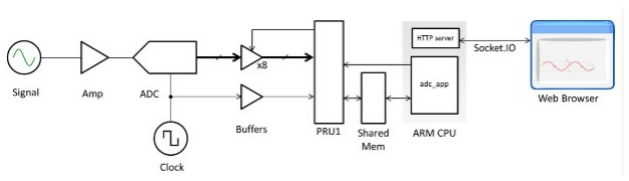
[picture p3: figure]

La señal es muestreada por el ADC (que usa un clk externo). A la salida paralela del ADC se usan buffers para mejorar el acoplamiento entre el ADC y la unidad PRU (Programmable Real-Time Unit) de la Beaglebone. Se crea una aplicación en Linux llamada adc_app, que toma la información de la unidad PRU y la almacena en una memoria compartida. Posteriormente esa información es organizada en un archivo csv y enviada vía web usando la tarjeta Beaglebone también como un servidor.

En la implementación del servidor se usa Node.JS, que es un entorno de programación del lado del servidor, y que usa Javascript como lenguaje de programación. Permite entradas y salidas de datos. Usa SocketIO para crear las entradas y salidas de datos. Socket.IO es una librería de Javascript que permite comunicaciones en tiempo real de aplicaciones web.

### 3. CARACTERÍSTICAS DEL PROYECTO

### 3.1 Características del ADC del ATSAM3N:

El procesador ATSAM3N0A de Atmel incluye:
- 16 canales multiplexados para ser usados con el ADC.
- El ADC incorporado es de modo común, es decir, su referencia de señal es la misma referencia de tierra del circuito (la misma tierra digital).
- Posee un pin de referencia de voltaje ADVREF que puede encontrarse en el rango de 2,6V a

3,6V.
- Resolución de 8 bits o 10 bits configurable por software.
- Registros de almacenamiento de datos individuales para cada canal
- Frecuencia de conversión de hasta 500KHz

El esquema del ADC es presentado a continuación:

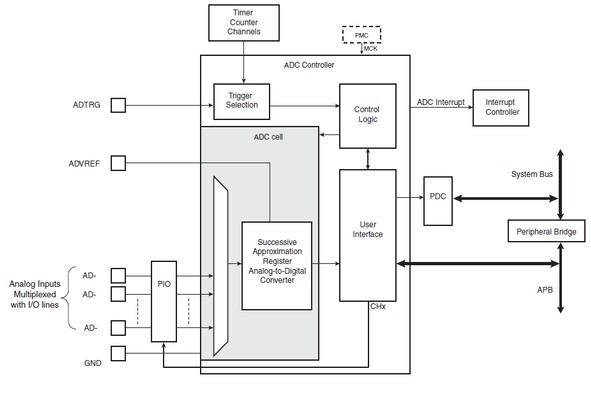
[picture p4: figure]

La MINI-STAMP posee un regulador de 3.3V, que sería la tensión de referencia para el ADC en el
pin | ADVREF.
Claramente este no es un ADC diferencial, por lo que no se puede realizar el sensado de señales negativas.
La diferencia de un ADC diferencial y un ADC común está explicada en:

http://electronics.stackexchange.com/questions/3727/what-is-a-differential-adc

Por tanto se requiere de un acoplamiento de la señal.

### 3.2 Acoplamiento de la señal:

Puesto que la señal a visualizar puede ser bipolar, se requiere realizar un acondicionamiento de esta para que pueda ser leída correctamente por el ADC, tal que no quede por fuera del rango de muestreo del ADC. Este acondicionamiento se puede realizar usando amplificadores operacionales.
OPCIÓN 1: Uso de 2 amplificadores, con polarización bipolar. El primero realiza un escalamiento de la señal, reduciendo su span y el segundo inserta un offset para no tener señales negativas. A continuación se muestra:

OPCIÓN 2:

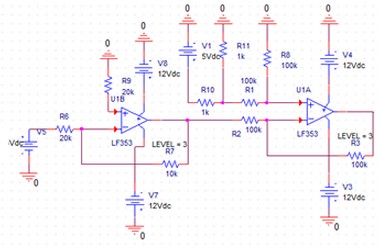
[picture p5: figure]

Uso de un solo amplificador operacional, usando una sola fuente de alimentación, en el cual se implementa al tiempo el escalamiento de la señal y el offset que se le debe dar, para evitar señales negativas entrantes al ADC.

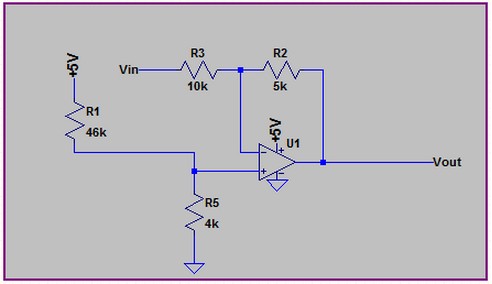
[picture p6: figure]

Claramente esta opción es mucho más sencilla y produce el mismo efecto requerido. TENER EN CUENTA: La impedancia de entrada de la OPCIÓN 2 es R3 (¿¿¿???), por lo que la relación de impedancias de la sonda y la resistencia de entrada es importante para el escalamiento de la señal en el osciloscópio.

Sondas Atenuadas: Poseen una impedancia asociada de aproximadamente 9Mohms. Los osciloscópios comunes poseen una impedancia de entrada de 1Mohm, por lo que la atenuación producida por la sonda (comúnmente x10) es el resultado del divisor de tensión entre las impedancias de la sonda y el osciloscópio. De esta manera, R3 debería ser de 1Mohm para poder usar sondas atenuadas, y así ampliar el rango de tensión posible por el ADC.

### 4. DESARROLLO

### 4.1 Pruebas con el ADC

Para poder usar el SAM3N, este requiere de un sistema operativo que lo controle. Se llama ChibiOS, que es un OS muy liviano y orientado a la programación de aplicaciones en tiempo real. Permite crear hilos de procesos paralelamente, y manejar todos los periféricos del SAM3N.

La aplicación que se desee implementar con el SAM3N se escribe en código C, y usando la cadena de herramientas de compilación para el SAM, se genera un archivo binario ch.bin, que es el que contiene tanto el OS que va a controlar el procesador, como el código de la aplicación que se desea correr.

Para pasar este archivo a la memoria del SAM, primero se copia en alguna parte de la SD, y luego se usa la aplicación “openocd” para enviar vía puerto serial, el ch.bin desde la memoria SD, a través del iMX, hasta la memoria del SAM.

La aplicación Openocd fue incluida dentro del sistema de archivos cuando fue creado.

Para el caso del uso del ADC, el ejemplo se encuentra en /ChibiOS_mini/demos/ARMCM3-SAM3N-EK/main.c; en esa carpeta también se encuentra el Makefile, así como todos los demás archivos y librerías provistas por Atmel para usar las múltiples funciones preprogramadas. Para compilar el código del ADC junto con el OS: $ make. Esto crea el ch.bin, que se pasa a la SD, junto con múltiples archivos de configuración del SAM, también presentes en la carpeta del main.c

Desde la terminal de la Mini-stamp, en la ubicación del ch.bin:

$ openocd -f stamp_mini_sam3n.cfg

Para crear el nodo de comunicación entre el SAM y el iMX, que va a ser un puerto serial:

$ mknod /dev/ttySP1 c 242

El “c” significa: comunicación tipo char: envío de datos por carácter, no por bloques. El puerto serial está por defecto configurado para una velocidad de transmisión de 38400 baudios, pero el ejemplo del ADC transmite a 115200 baudios. Para cambiar esto

$ stty -F /dev/ttySP1 115200

Ahora sí, se puede ver lo que está recibiendo el puerto:

$ cat /dev/ttySP1

El proceso se corta con ctrl + C.

### 4.2 CAPTURA Y ALMACENAMIENTO DE DATOS

Se desea desarrollar un programa en código C que lea la información del puerto serial, y la almacene en un archivo en formato .json, que luego será importado por Node.js para ser graficado en el navegador. La info que está siendo enviada por el puerto serial son los datos del ADC del SAM3N.

El núcleo de este código está en los parámetros de configuración del puerto. Se debe incluir la librería <termios.h>, que contiene la estructura "termios" con todos los parámetros de configuración del puerto. Para nuestra aplicación los parámetros que se deben cambiar son: la velocidad de transmisión (115200 baudios), si hay o no bit de paridad (sí hay), y la cantidad de bits a transmitir (8 en nuestro caso).

Luego, se lee iterativamente el archivo asociado al puerto serial, en el cual se encuentran los datos entrantes en un búffer. Estos datos se van organizando según la sintaxis del formato de archivos .json (www.json.org) en forma de objetos, en un archivo de registro que posteriormente será leido por Node.js.

### 4.3 JAVASCRIPT

Una vez en la tarjeta posee un servidor web es momento de enfocarse en la creación de una página web donde se muestren los datos obtenidos con la tarjeta.

Para poder realizar la visualización de la información en algún dispositivo se utilizó Javascript. Este es un lenguaje de programación orientado a objetos que es comúnmente utilizado dentro de la programación de páginas web cuyo código es generalmente ejecutado en el navegador. Para poder utilizar Javascript por fuera del navegador se utiliza Node.js, un entorno de programación orientado a eventos basado en Javascript, que en lugar de ejecutarse en el navegador se ejecuta del lado del servidor. Además de ser un entorno, Node.js también es utilizado como librería de Javascript.

Al utilizar Node.js lo que se hace es implementar un servidor HTTP, de tal manera que nuestra aplicación pueda ser observada por el usuario y que esta sea capaz de responder a las diferentes peticiones que pueden surgir de la interacción del usuario con la página web.

Para lograr esto, la aplicación se va a dividir en 3 programas Javascript diferentes, el primero (generalmente llamadoserver.js) nos va a permitir implementar e iniciar el servidor, especificando una dirección IP y un puerto de acceso, y además va a recibir las diferentes peticiones del usuario. El segundo archivo (generalmente llamado router.js) se va a hacer cargo de direccionar las peticiones recibidas, asignando la petición al manejador correspondiente o avisando al usuario que
la | petición | realizada | no | posee | ninguna | manejador | que | pueda | tratarla.
Finalmente el tercer archivo (generalmente llamado requestHandler.js) se encarga de tratar las peticiones que le son enviadas, es en este archivo donde, según la petición que se realice, se especifica el código HTML que es el que realiza la interfaz gráfica de la página web a partir de la cual el usuario esta interactuando con la aplicación. En este archivo no solo se tratan las diferentes peticiones sino que se definen los diferentes manejadores que son usados en la aplicación.

Cabe resaltar que esta no es la única forma en que una aplicación web se puede desarrollar, el formato que se adoptó está basado en lo tratado por el libro The Node Beginner Book, escrito por Manuel Kiessling.
(verhttp://www.nodebeginner.org)

La primera tarea a realizar era la creación del archivo server.js, en esta se definía la dirección IP y el puerto en el q si iba a trabajar. La dirección se eligió de acuerdo con la que ya había sido seleccionada durante la configuración de los diferentes archivos de la tarjeta para habilitar la red. El puerto elegido fue el 8888, ya que en sistemas operativos basados en Linux no es posible hacer enlaces a puertos menores de 1024 a menos que se habiliten ciertas opciones para las cuales el kernel de la tarjeta no tiene soporte.

var http = require("http");

var url = require("url");

function iniciar(route, handle) {

function onRequest(request, response) {

var pathname = url.parse(request.url).pathname;

console.log("Request for " + pathname + " received.");

request.setEncoding("utf8");

request.addListener("end", function() {

route(handle, pathname, response);

});

}

http.createServer(onRequest).listen(8888);

console.log("Servidor Iniciado.");

}

exports.iniciar = iniciar;

A continuación se creó el archivo router.js, cuyo rol ya fue explicado anteriormente y cuyo código se muestra a continuación.

function route(handle, pathname, response) {
console.log("A punto de rutear una peticion para " + pathname); if (typeof handle[pathname] === 'function') { handle[pathname](response);
} else {
console.log("No se ha encontrado manipulador para " + pathname); response.writeHead(404, {"Content-Type": "text/html"}); response.write("404 No encontrado");
response.end();
}
}

exports.route = route;

Finalmente se encuentra requestHandler.js, que es el archivo más extenso y el que más complicaciones puede traer, ya que en este es que se describen las funciones que se deben realizar según las solicitudes realizadas y además se describe el código HTML que define lo que se va a mostrar en la página web con la cual el usuario va a interactuar. La aplicación a realizar se basa básicamente en hacer la toma de datos a través de la tarjeta y poder graficar los resultados obtenidos, razón por la que se debía hacer énfasis en aprender a graficar y a leer datos de archivos preestablecidos.

Para la parte de realizar gráficas existen dos opciones básicas que se pueden utilizar de la librería jquery: las librerias Floty Smoothie. Estas dos librerías permiten crear gráficas que se van a ubicar en marcos creados anteriormente, para la aplicación se decidió utilizar Flot.js porque, si bien las dos son fáciles de utilizar, ésta librería posee mayor documentación sobre cómo realizar gráficas cuando los datos se encuentran en archivos externos al código.

Para la parte de adquisición de datos se decidió que los resultados obtenidos en la tarjeta se guardarían en un archivo.json. Usando la librería jquery existe la función Ajax, la cual puede tomar la dirección de un archivo de diversos tipos y retornar su contenido para que este sea tratado en la aplicación. Este fue el procedimiento a realizar, sin embargo en este caso el archivo a leer se encontraba en la dirección "http://192.168.50.1", mientras que la aplicación se encuentra en la dirección "http://192.168.50.1:8888".

Cuando las direcciones de un archivo que desea ser leído utilizando Ajax no se encuentra en la dirección base donde la función es utilizada se produce un error de dominios cruzados llamado " Access-Control-Allow-Origin", que básicamente no permite por motivos de seguridad abrir archivos de otras direcciones web. Para solucionar este inconveniente se debe agregar un archivo llamado ".htaccess" a la dirección donde se encuentra el archivo a ser leído, para convertir el error en flag, y además se debe ejecutar la aplicación en una ventana de Google-Chrome donde se hallan deshabilitado ciertos elementos. El contenido del archivo .htaccess es:

Header set Access-Control-Allow-Origin "*"

Para lograr esto se escribe en terminal:

$ google-chrome --disable-web-security

Volviendo al archivo requestHandler.js, luego de haber solucionado los problemas expuestos, en este archivó se diseñó una página principal que permite acceder a la gráfica resultante mediante un botón y esta página donde se muestra la señal lleva otra página que permite volver al inicio. El código de este archivo se muestra a continuación:

var fs = require('fs');
var server = require("./server"); var router = require("./router"); var ADC_DEV_NAME = '/proyecto/salida';

function iniciar(response) {
console.log("Manipulador de Peticion 'iniciar' fue llamado."); fs.writeFile(ADC_DEV_NAME, "Y" );

var body = '<html>'+

'<head>'+
'<title>Digital Oscilloscope - Embedded Systems</title>'+
'<meta http-equiv="Content-Type" content="text/html; charset=UTF-8" />'+ '<link href="http://192.168.50.1/lib/examples.css" rel="stylesheet" type="text/css">'+
'<script language="javascript" type="text/javascript" src="http://192.168.50.1/lib/jquery.js"></script>'+
'<script language="javascript" type="text/javascript" src="http://192.168.50.1/lib/jquery.flot.js"></script>'+'</head>'+
'<body>'+
'<div id="header">'+
'<h3>Osciloscopio Digital - Sistemas Embebidos</h3>'+ '</div>'+

'<div id="content">'+

'<b>Presentaci&oacuten</b>'+ '<br/>'+
'<br/>'+

'<p>Mediante esta aplicaci&oacuten se pretende facilitar la realizaci&oacuten de pr&aacutecticas de laboratorio de F&iacutesica en colegios.'+
' Esta p&aacutegina funciona como un osciloscopio digital, la tarjeta a la cual est&aacute asociada la p&aacutegina se encarga de realizar'+
' la adquisici&oacuten de datos y el env&iacuteo de los mismos para que sean graficados en este lugar.</p>'+
'<br/>'+

'<p>Por favor conecte el dispositivo de medici&oacuten a los terminales del circuito que desea probar. Una vez haya verificado que las '+
'conexiones realizadas son correctas y que los valores esperados a la salida no sobrepasan los rangos de operaci&oacuten del dispositivo '+ 'oprima el bot&oacuten <b><i>Graficar Salida</i></b> para que la adquisici&oacuten de datos comience. Este bot&oacuten lo llevara a una nueva '+ 'p&aacutegina donde usted podr&aacute observar la señal de salida medida de su circuito.</p>'+ '<br/>'+

'<p>'+
'<form action="/subir" method="post">'+
'<input type="submit" value="Graficar Salida" FONT-SIZE= 12px />'+ '</form>'+
'</p>'+
'</div>'+
'</body>'+

'</html>';

response.writeHead(200, {"Content-Type": "text/html"}); response.write(body);
response.end();
}

function subir(response,output) {
console.log("Manipulador de Peticion 'subir' fue llamado."); console.log("Taking Samples from ADC: "); fs.writeFile(ADC_DEV_NAME, "Y" );

var body = '<html>'+
'<head>'+
' | <title>Results: Graphs</title>'+
' | <meta http-equiv="Content-Type" content="text/html; charset=utf-8">'+
' | <link href="http://192.168.50.1/lib/examples.css" rel="stylesheet"
type="text/css">'+
' | <script language="javascript" type="text/javascript"
src="http://192.168.50.1/lib/jquery.js"></script>'+
' | <script language="javascript" type="text/javascript"
src="http://192.168.50.1/lib/jquery.flot.js"></script>'+
' | <script type="text/javascript">'+
' | $(function() {'+
' | var options = {'+
' | lines: {'+
' | show: true'+
' | },'+
' | points: {'+
' | show: true'+
' | },'+
' | xaxis: {'+
' | tickDecimals: 0,'+
' | tickSize: 1'+
' | }'+
' | };'+
' | var data = [];'+
' | $.plot("#placeholder", data, options);'+
| // Fetch one series, adding to what we already have
' | var alreadyFetched = {};'+

' | $("button.fetchSeries").click(function () {'+
' | var button = $(this);'+
| // Find the URL in the link right next to us, then fetch
the data
' | var dataurl = button.siblings("a").attr("href");'+
' | function onDataReceived(series) {'+
| // Extract the first coordinate pair; jQuery
has parsed it, so
| // the data is now just an ordinary JavaScript
object
' | var firstcoordinate = "(" + series.data[0][0]
+ ", " + series.data[0][1] + ")";'+
' | button.siblings("span").text("Fetched " + se-
ries.label + ", first point: " + firstcoordinate);'+
| // Push the new data onto our existing data ar-
ray
' | if (!alreadyFetched[series.label]) {'+
' | alreadyFetched[series.label] = true;'+
' | data.push(series);'+
' | }'+
' | $.plot("#placeholder", data, options);'+
' | }'+
' | $.ajax({'+
' | url: dataurl,'+
' | type: "GET",'+
' | dataType: "json",'+
' | success: onDataReceived'+
' | });'+
' | });'+
| // Load the first series by default, so we don't have an empty plot
' | $("button.fetchSeries:first").click();'+
' | });'+
' | </script>'+
'</head>'+

'<body>'+

' | <div id="header">'+
' | <h2>Resultados - Gr&aacuteficas</h2>'+
' | </div>'+
' | <div id="content">'+
' | <div class="demo-container">'+
' | <div id="placeholder" class="demo-
placeholder"></div>'+
' | </div>'+
' | <p>'+
' | <button class="fetchSeries">Graficar</button>'+
' | [ <a href="http://192.168.50.1/data.json"
target="_blank"> | see data</a> ]'+
' | <span></span>'+
' | </p>'+
' | <p>'+
' | <button class="back">Actualizar Datos</button>'+
' | [ <a href="/salir">reload</a> ]'+
' | </p>'+
' | </div>'+

'</body>'+
'</html>';
response.writeHead(200, {"Content-Type": "text/html"}); response.write(body);
response.end();
}

function salir(response) {
console.log("Manipulador de Peticion 'iniciar' fue llamado."); fs.writeFile(ADC_DEV_NAME, "Q" );
subir(response);
}

var handle = {}
handle["/"] = iniciar;
handle["/iniciar"] = iniciar; handle["/subir"] = subir;
handle["/salir"]=salir;

server.iniciar(router.route, handle);

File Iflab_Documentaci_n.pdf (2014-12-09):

´

# Indice general

1. Linux Embebido | 3
2. Configuración HostPot | 13

ÍNDICE GENERAL | 2

Capítulo 1

# Linux Embebido

### Índice

### 1.3. Herramientas de Cross-Compilación y Sistema de Archivos . . . . 6

## 1.1. Introducción

En este capitulo se muestra como se debe realizar para generar las herramientas de cross-compilación , sistema de archivos, imagen del kernel y la imagend del Bootloader para guardarlas en una memoria SD y así poder iniciar Linux Embebido en el IfLab.

Para la generación del las herramientas de cross-compilación y el sistema de archivos se uso BuildRoot. Para crear la imagen del kernel se descargo la versión 2.6.35 y para generar el u-boot se descargo el imx-bootlest-src versión 10.05.02.

1.2 Formato de la Tarjeta SD | 4

## 1.2. Formato de la Tarjeta SD

Para poder crear una distribución de Linux Embebido para la IfLab es necesario dar un formato especial a una memoria SD, pues este sera el disco duro del sistema embebido.

Primero es necesario tener una memoria microSD de al menos 2GB de capacidad. Para darle el formato se deben seguir las siguientes instrucciones.

Primero se debe conectar la memoria al computador. Para mirar como es el nombre de esta memoria se ejecuta el comando dmesg. Para este caso el se tomara que el computador la detecto como /dev/sdb.

Primero se debe desmontar la memoria, para esto se ejecuta el siguiente comando

1 [˜]$ sudo umount /dev/sdb*

Luego con la aplicación fdisk se le dará formato a cada una de las particiones, para esto se ejecuta:

1 [˜] $ sudo fdisk /dev/sdb

Esta aplicación obre una interfaz en la consola, el primer paso para realizar en fdisk es borrar las particiones existentes en la memoria. Esto se hace:

1 | Command (m for help): d
2 | Partition number (1-4):

En el campo de Partition number se debe ingresar todos los numero de las particiones hasta que no exista ninguna, para revisar eso basta poner el Command la letra p.

Luego de tener la tabla de particiones vacía se debe crear una primera partición de 200MB. Para esto en fdisk se realiza:

1 | Command (m for help): n | //Comando para crear una nueva particion
2 | Partition type:
3 | p | primary (0 primary, 0 extended, 4 free)
4 | e | extended
5 | Select (default p): p | //Selecionar tipo de particion Primaria
6 | Partition number (1-4, default 1): 1 | //Nombrar la particion con el numero 1

Luego de esto el programa despliega desde donde es el inicio de la partición, para asignar el

1.2 Formato de la Tarjeta SD | 5

valor por defecto solo hay que oprimir la tecla Enter. Luego se le debe indicar el final de la partición para esto se debe ingresar +200M. Estas instrucciones en la interfaz se ve como:

1 | First sector (2048-7626751, default 2048): | //Presionar Enter
2 | Using default value 2048
3 | Last sector, +sectors or +size{K,M,G} (2048-7626751, default 7626751):+200M
4 | Partition 1 of type Linux and of size 200 MiB is set

Ahora se debe crear la segunda partición en el espacio que queda en la microSD, para esto se realiza:

1 | Command (m for help): n | //Comando para crear una nueva particion
2 | Partition type:
3 | p | primary (0 primary, 0 extended, 4 free)
4 | e | extended
5 | Select (default p): p | //Selecionar tipo de particion Primaria
6 | Partition number (1-4, default 1): 2 | //Nombrar la particion con el numero 2

Luego se fija y el final de la partición por defecto:

1 | First sector (411648-7626751, default 411648):
2 | Using default value 411648
3 | Last sector, +sectors or +size{K,M,G} (411648-7626751, default 7626751):
4 | Using default value 7626751
5 | Partition 2 of type Linux and of size 3.5 GiB is set

Ahora es necesario cambiar el tipo de partición 1 a OnTrack DM6 (53), en el programa se ejecuta:

1 | Command (m for help): | t | // Comando para Cambiar tipo de Particion
2 | Partition number (1-4): 1
3 | Hex code (type L to list codes): 53
4 | Changed system type of partition 1 to 53 (OnTrack DM6 Aux3)

Se realiza el mismo procedimiento para la partición 2 pero esta se cambia a Linux (83):

1 | Command (m for help): | t | // Comando para Cambiar tipo de Particion
2 | Partition number (1-4): 2
3 | Hex code (type L to list codes): 83
4 | Changed system type of partition 1 to 83 (Linux)

Al final de este proceso la tabla de particiones se debe ver de la siguiente manera:

1 | Command (m for help): | p | // Comando para ver tabla
2 | Device Boot | Start | End | Blocks | Id | System

1.3 Herramientas de Cross-Compilación y Sistema de Archivos | 6
3 | /dev/sdb1 | 2048 | 411647 | 204800 | 53 | OnTrack DM6 Aux3
4 | /dev/sdb2 | 411648 | 7626751 | 3607552 | 83 | Linux

Para finalizar la creación de las particiones se deben guardar los cambios de la tabla de particiones, para esto se ejecuta:

1 | Command (m for help): w | //Comando para Guardar la tabla
2 | The partition table has been altered!

3
4 | Calling ioctl() to re-read partition table.
5 | Syncing disks.

Teniendo lista las particiones de la microSD es necesario dar formato a la segunda partición, para esto se ejecuta:

1 [˜]$ sudo mkfs.ext3 /dev/sdb2

Teniendo listo el formato de la segunda partición la tarjeta microSD esta lista para almacenar el bootlader, la imagen del kernel y el sistema de archivos para la distribución de Linux Embebido.

## 1.3. Herramientas de Cross-Compilación y Sistema de Archivos

Buildroot es un conjunto de Makefiles y parches para la generación fácil de Linux embebido. Puede generar todas las herramientas de cross-compilación, el sistema de archivos, la imagen del kernel y la imagen del Bootlader. Esta herramienta tiene soporte para arquitecturas: ARM, MIPS, X86, PowerPC, entre otras. Sus características mas importantes son, la facilidad de configuración, debido las diferentes interfaces de configuración(menuconfig) que presenta y el soporte a cientos de paquetes para aplicaciones y librerías para ser usadas en espacio de usuario. [1]

1.3 Herramientas de Cross-Compilación y Sistema de Archivos | 7

### 1.3.1. Descarga y configuración

Para realizar la descarga de Buildroot se puede realizar siguiendo los pasos que se muestran la pagina oficial de esta proyecto¹
, sin embargo para IfLab se encuentra disponible una versión disponible en el siguiente repositorio:

1 https://bitbucket.org/cicamargoba/mini-open/downloads/

Allí se descarga el archivo buildroot-2013.08.1.tar.bz2. Luego de descomprimir este archivo se debe ubicar desde la consola en esa carpeta. En conosola se ejecuta el siguiente comando:

1 [buildroot-2013.08.1]$ make menuconfig

Este comando abre la interfaz de configuración de BuildRoot, allí se pueden realizar todas tipo configuraciones para la creación de las herramientas de cross-compilación y los paquetes y librerias que se añadirán al sistema de archivos. En esta distribución de BuildRoot ya se le ha dado soporte a aplicaciones como : boa, hostapd, minicom, node, openocd, dhcp, entre otras. Cuando se ejecuta este comando en su consola se debe mostrar una interfaz de configuración como se muestra en la Figura 1-1.

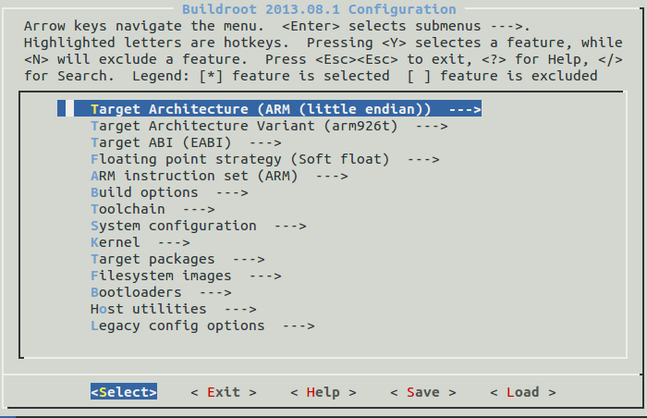
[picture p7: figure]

Figura 1-1: Interfaz de configuración de Buildroot

En la configuración que trae por defecto ya se encuentran realizadas las configuraciones de la arquitectura y la generación de las herramientas de cross-compilación.

Es necesario ingresar a la opción de System Configuration para realizar la configuración del puerto donde se ubicara al consola, la velocidad de este puerto, además de configuraciones

1http://buildroot.uclibc.org/download.html

1.3 Herramientas de Cross-Compilación y Sistema de Archivos | 8

como el nombre del Usuario-Host y contraseña. A continuación se muestra como debe quedar las configuraciones del sistema.

1 | System configuration | --->
2 | (buildroot) System hostname
3 | (Welcome to Buildroot) System banner
4 | Passwords encoding (md5) | --->
5 | /dev management (Static using device table) | --->
6 | Init system (Busybox) | --->
7 | (system/device_table.txt) Path to the permission tables
8 | (system/device_table_dev.txt) Path to the device tables
9 | Root FS skeleton (default target skeleton) | --->
10 | () | Root password
11 | (ttyAM0) Port to run a getty (login prompt) on
12 | Baudrate to use (115200) | --->
13 | (vt100) Value to assign the TERM environment variable
14 | [*] remount root filesystem read-write during boot
15 | () | Root filesystem overlay directories
16 | () | Custom scripts to run before creating filesystem images
17 | () | Custom scripts to run after creating filesystem images

En la opción Port to run a getty se especifica el puerto serial donde ubica la consola, por tanto es necesario cambiar de ttyS0 a ttyAM0. Este cambio es necesario debido a que el kernel 2.6.35 apunta al puerto serial con ese nombre. Sin embargo si se usa una versión de kernel 3.7 se debe cambiar por ttyAMA0.

### 1.3.2. Módulos de nodeJs

Además de realizar configuraciones del sistema la interfaz de configuración de BuilRoot permite agregar o quitar aplicaciones y librerías del sistema de archivos. En este caso es necesario agregar módulos de nodeJs para realizar el desarrollo de la interfaz gráfica.

Para realizar esta configuración se debe ubicar en la opción de nodeJs.

1 | Target Package ->
2 | Interpreter languages and scripting | --->
3 | [*]nodejs
4 | Module Selection | --->
5 | [*] NPM for the target
6 | [*] Express web application framework
7 | [*] CoffeeScript
8 | (socket.io jade serialport) Additional modules

Los módulos adicionales que se necesitan para node se deben escribir en la opción de Additional modules. Para este caso se adicionaron los modulos: socket.io, jade, serialport.

1.3 Herramientas de Cross-Compilación y Sistema de Archivos | 9

Con estas modificaciones ya esta listo para realizar su compilación, esto se reliza ejecutando el siguiente comando en consola:

1 [buildroot-2013.08.1]$ make

Este proceso dura algunas horas, dependiendo de la conexión a internet y la capacidad de su computador de compilar todos los paquetes. Durante este proceso se presenta un error en la compilación de la aplicación openocd. Cuando esto ocurra se debe ejecutar en consola la siguiente instrucción:

1 [buildroot-2013.08.1]$ make CFLAGS=-std=gnu99

Luego si se presenta algún error solo basta ejecutar en consola de nuevo el siguiente comando:

1 [buildroot-2013.08.1]$ make

Cuando todo haya conculido en la consola se debe ver el siguiente mensaje:

1 | [buildroot-2013.08.1]$ >>> | Generating root filesystem image rootfs.tar

Esto indica que todo el proceso de generación de herramientas y compilación de aplicaciones ha concluido. Este proceso crea un archivo llamado rootfs.tar con todo el sistema de archivos ubicado en buildroot-2013.08/output/images.

### 1.3.3. Herramientas de Cross-compilación

Las herramientas de Cross-Compilación se encuentran en el directorio: buildroot-2013.08.1 /output/host/usr/bin/.Es necesario crear un link al enlazador, esto se realiza con los siguientes comandos:

1 | [buildroot-2013.08.1]$ cd output/host/usr/bin/
2 | [bin]$ ln -s | arm-buildroot-linux-uclibcgnueabi-ld.real arm-linux-ld.real

Para usar estas herramientas de cross-compilación se debe agregar este directorio a la variable de entorno $P AT H. Esto se logra agregando la siguiente instrucción en el archivo .bashrc.

1 export PATH=$PATH:/path_buildroot/buildroot-2013.08.1/output/host/usr/bin

1.4 Compilación del Kernel y del Imx-Bootlest | 10

Los ejecutables del croos-compilador tienen el prefijo arm-linux-. Teniendo esto listo ya se pueden cross-compilar las aplicaciones.

### 1.3.4. Almacenamiento Sistema de Archivos

Teniendo listo el sistema de archivos generado por BuildRoot, solo queda guardar este en la memoria microSD, para esto se debe ir al directorio donde se encuentra el archivo rootfs.tar. Para descomprimir el sistema de archivos en la tarjeta se ejecuta:

1 | [images] $ sudo | tar -jxvf rootfs.tar | -C /media/disk/

De esta forma ya se tiene almacenada el sistema de archivos en la memoria microSD.

## 1.4. Compilación del Kernel y del Imx-Bootlest

Con las herramientas de cross-compilación listas, se puede compilar la imagen del kernel de linux. Primero se deben descargar los archivos fuente de la versión de kernel a compilar, en este caso se uso el kernel 2.6.35, debido a que tiene soporte de audio para el procesador IMX233. La descarga se puede realizar del pagina web de desarrollo del kernel de Linux² .
Sin embargo se puede descargar una versión de kernel ya configurado para esta arquitectura, esta versión se encuentra en el siguiente repositorio:

1 https://bitbucket.org/cicamargoba/mini-open/downloads/

El archivo se llama linux-2.6.35.3.tar.bz2, se debe descargar y descomprimir. Luego para revisar la configuración de cross-compilación se ejecuta en consola el siguiente comando:

1 [linux-2.6.35.3]$ make ARCH=arm CROSS_COMPILE=arm-linux- menuconfig

Se debe abrir en la consola un interfaz de configuración como la que se muestra en la Figura 1-2

Allí se configura para que tipo de arquitectura se esta compilando, las opciones de arranque y cuales drivers se deben incluir en la compilación.

2https://www.kernel.org/

1.4 Compilación del Kernel y del Imx-Bootlest | 11

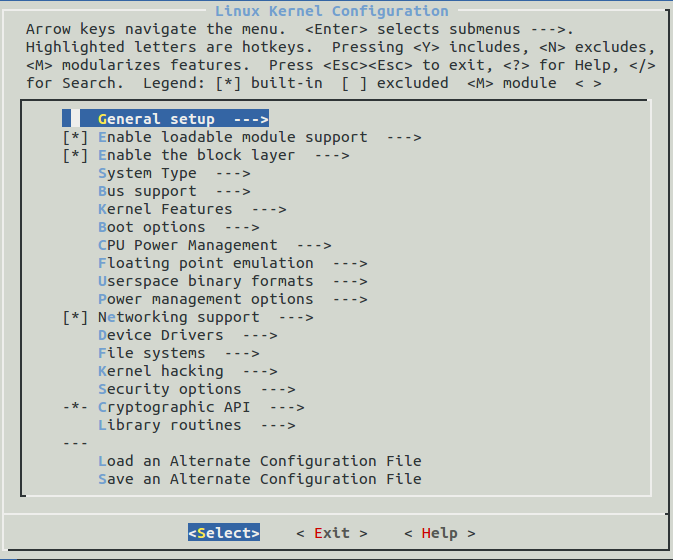
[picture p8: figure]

Figura 1-2: Interfaz de configuración del Kernel 2.6.35

### 1.4.1. Driver de la Llave WiFi RTL8192CU

Para darle soporte a esta Llave Wifi debe seleccionar las siguientes opciones:

1 | Device Drivers | --->
2 | [*] Networking support | --->
3 | [*] | Wireless LAN | --->
4 | <*> | Realtek 8192C USB WiFi

Esta llave WiFi, por defecta esta configurada para realizar metodos de ahorro de energia, sin embargo esto hace que a la hora de estar conectado se aumenten los tiempos de ejecución de la aplicación, para esto se debe deshabilitar esta opción de ahorro de energía. Para esto sse debe abrir el archivo Makefile del driver:

1 [linux-2.6.35.3]$ gedit drivers/net/wireless/rtl8192cu/Makefile

En este archivo se debe cambiar la opción de CONFIG POWER SAVING:

1 | Cambiar : CONFIG_POWER_SAVING = y
2 | por: CONFIG_POWER_SAVING = n

1.4 Compilación del Kernel y del Imx-Bootlest | 12

### 1.4.2. Compilación del Kernel 2.6.35

Con la configuración completa, es hora de realizar la compilación del kernel. Para esto se debe ejecutar en la consola el siguiente comando:

1 [linux-2.6.35.3]$ make ARCH=arm CROSS_COMPILE=arm-linux-

Dependiendo de las especificaciones de su computador el proceso tarda unos minutos. Cuando termine este proceso se debe observar el siguiente mensaje:

1 Kernel: arch/arm/boot/zImage is ready

En esta linea se informa donde esta ubicado el archivo con la imagen comprimida del Kernel.

### 1.4.3. Compilación del Imx-Bootlest

Teniendo lista la imagen del Kernel es necesario crear el Boot loader. Para esto es necesario descargar del repositorio el archivo Imx-bootlets-src-10.05.02.tar.bz2. Luego de descomprimir su contenido se ubica la consola en ese directorio.

Primero es necesario crear un link de elftosb2, para eso solo es necesario ejecutar la siguiente instrucción:

1 [Imx-bootlets-src-10.05.02] $ sudo ln -s ‘pwd‘/elftosb2 /usr/sbin/

Ahora se puede realizar la compilación del Boot-loader y el almacenamiento en la primera partición de la microSD.Para esto se ejecuta:

1 [Imx-bootlets-src-10.05.02] $ make ARCH=mx23 CROSS_COMPILE=arm-linux-

Al finalizar este proceso se guardo el Boot-loader en la primera partición y la tarjeta microSD esta lista para conectar en IFLab.

Capítulo 2

# Configuración HostPot

### Índice

## 2.1. Introducción

## 2.2. Cross-Compilación Hostapd

Hostapd es un demonio en espacio de usuario para crear puntos de acceso y servidores de autenticación. Este programa implementa el estándar IEEE 802.11 para puntos de acceso, el IEEE 802.1X/WPA/WPA2/EAP de autenticación.[3]

Debido al uso de la Llave Wifi RTL8192CU se debe usar una versión de Hostapd especial que ofrece el fabricante de la llave, esta versión esta especialmente modificada para que funcione con esta llave wifi.

En el repositorio se encuentra un archivo llamado Hostapd.tar donde se encuentra esta versión especial lista para ser cross-compilada. Luego de realizar la descarga y descomprimir el archivo, se debe revisar el Makefile y debe indicar que se va realizar la compilación con el prefijo arm-linux-gcc.

2.3 Configuración en el Sistema de archivos | 14

Al finalizar este proceso se crea un archivo ejecutable llamado hostapd, este ejecutable se debe copiar en la carpeta /usr/sbin del sistema de archivos del Embebido.

## 2.3. Configuración en el Sistema de archivos

### 2.3.1. Asignación de dirección IP

Teniendo la imagen del kernel y el sistema de archivos andando se debe verificar que nombre usa el sistema para identificar la llave WiFi. Para esto se ejecuta:

1 | [˜]# iwconfig
2 | wlan0 | IEEE 802.11b | ESSID:"IfLab" | Nickname:"<WIFI@REALTEK>"
3 | Mode:Master | Frequency:2.412 GHz | Access Point: 44:33:4C:61:C3:18
4 | Bit Rate:11 Mb/s | Sensitivity:0/0
5 | Retry:off | RTS thr:off | Fragment thr:off
6 | Encryption key:off
7 | Power Management:off
8 | Link Quality:0 | Signal level:0 | Noise level:0
9 | Rx invalid nwid:0 | Rx invalid crypt:0 | Rx invalid frag:0
10 | Tx excessive retries:0 | Invalid misc:0 | Missed beacon:0

Ahora es necesario subir la la interfaz WiFi y asignarle una dirección IP, para esto se ejecuta en la consola:

1 [˜]# ifconfig wlan0 192.168.50.1 up

### 2.3.2. Configuración Hostapd

Teniendo la la aplicación hostapd lista y la interfaz de WiFi configurada, se deben crear los archivos de configuración y así crear el punto de acceso en el IfLab.

Primero se debe crear el archivo de configuración del hostapd. Primero se crea una carpeta llamada hostapd en la carpeta etc del sistema de archivos.

1 [etc]# mkdir hostapd

En esta carpeta se crea un archivo llamado hostapd.conf el cual contiene la siguiente información:

2.3 Configuración en el Sistema de archivos | 15
1 | [etc]# more hostapd.conf
| interface=wlan0
2 | driver=rtl871xdrv
3 | ssid=IfLab
4 | channel=1
5 | bridge=0

En este archivo se especifica la interfaz wifi que se va usar. Se le debe especificar cual driver debe usar para implementar el punto de acceso para esta llave WiFi es rtl871xdrv. En este archivo también se define el nombre de la red y el canal donde se va ubicar la red. Para correr la aplicación con esta configuración se ejecuta:

1 [˜]# hostapd /etc/hostapd/hostapd.conf &

Al terminar la ejecución ya esta creado el demonio del hostpot, ya la red esta creado, sin embargo la conexión se debe realizar manual pues aún no se ha configurado el servidor DHCP, para la asignación automática de IP.

### 2.3.3. Configuración Servidor DHCP

En una red de comunicaciones es necesario asignar direciones IP a la hora de establecer una conexión, ISC-DHCP es una aplicación que ofrece la asignación de estas direcciones de forma fácil y rápida. Este es un programa .open source”que implementa un protocolo de configuración dinámica en el host para conectar a un una red IP.[2]

Primero se debe crear un archivo donde indique cual de las interfaces de red usara por defecto. Para esto en el sistema embebido se ejecuta:

1 | [etc]# mkdir default | //Crear carpeta
2 | [default]# more isc-dhcp-server //Muestra el contenido del archivo
3 | INTERFACES="wlan0"

Luego en la carpeta /etc/dhcp se debe crear un archivo llamado dhcp.conf. Este archivo contiene:

1 | [dhcp] # more dhcpd.conf
2 | subnet 192.168.50.0 netmask 255.255.255.0 {
3 | range 192.168.50.5 192.168.50.20;
4 | option domain-name-servers 192.168.50.1, 192.168.50.1;option routers 192.168.50.1;
5 | }

2.3 Configuración en el Sistema de archivos | 16

Teniendo la configuración lista para correr el servidor DHCP se debe ejecutar:

1 | [˜] # touch /var/lib/dhcp/dhcpd.leases &
2 | [˜] # dhcpd -cf /etc/dhcp/dhcpd.conf wlan0 &

En este momento ya esta corriendo el servidor DHCP y la conexión a la red inalámbrica se realiza de forma automática.

### 2.3.4. Inicio automático

En este momento ya esta configurado tanto el punto de acceso a la red como el servidor de direcciones IP, solo queda configurar el sistema para que inicie automáticamente y no se tenga que ejecutar de nuevo las instrucciones descritas anteriormente. Para esto se debe crear un nuevo archivo en /etc/init.d.

El archivo debe tener:

1 | [˜] # more /etc/init.d/S51hostapd
2 | ifconfig wlan0 192.168.50.1 &
3 | hostapd /etc/hostapd/hostapd.conf &
4 | touch /var/lib/dhcp/dhcpd.leases &
5 | dhcpd -cf /etc/dhcp/dhcpd.conf wlan0 &

Ademas se le deben dar permiso de ejecución a este archivo, para esto se ejecuta:

1 [˜] # chmod +x /etc/init.d/S51hostapd

De esta forma queda configurada el punto de acceso en el IfLab.

# Bibliografía

[1] BuildRoot. BuildRoot About. 2014. url: http : / / buildroot . uclibc . org / about.html (visitado 28-05-2014).
[2] Internet Systems Consortium. ISC-DHCP About. 2014. url: http://www.isc.org/downloads/dhcp/ (visitado 28-05-2014).
[3] Hostapd. Hostapd About. 2014. url: http://hostap.epitest.fi/hostapd/(visitado 28-05-2014).

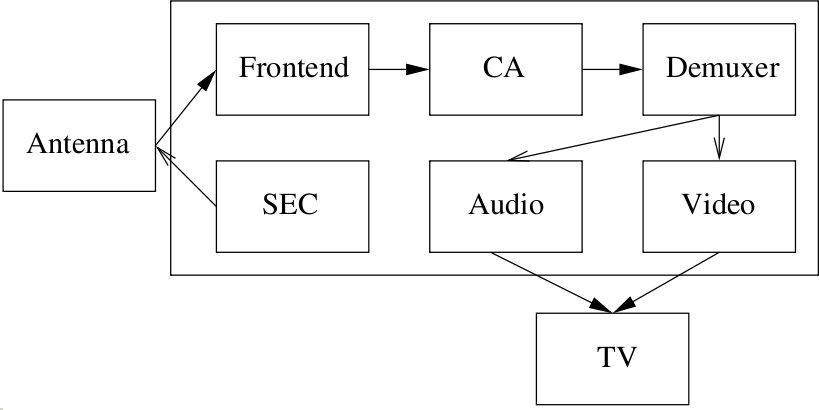
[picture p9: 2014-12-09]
linux-2.6.35.3/Documentation/DocBook/dvb/dvbstb.png

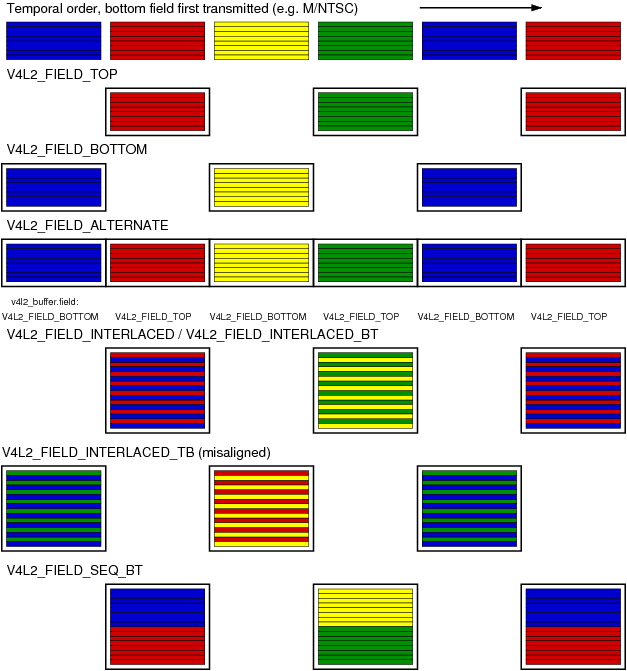
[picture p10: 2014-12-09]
linux-2.6.35.3/Documentation/DocBook/v4l/fieldseq_bt.gif

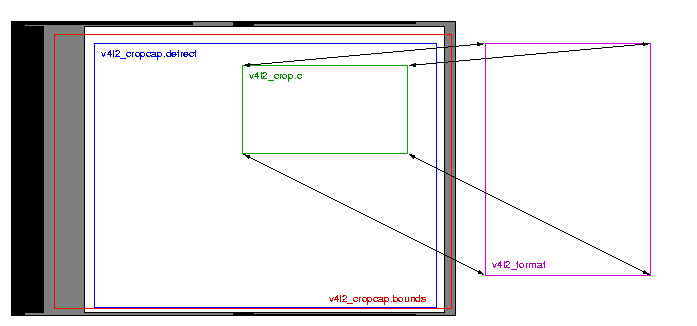
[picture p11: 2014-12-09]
linux-2.6.35.3/Documentation/DocBook/v4l/crop.gif

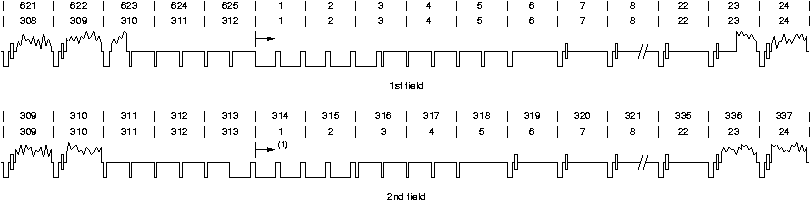
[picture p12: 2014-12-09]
linux-2.6.35.3/Documentation/DocBook/v4l/vbi_625.gif

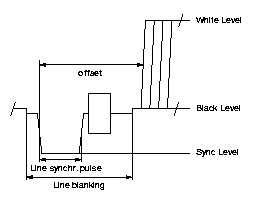
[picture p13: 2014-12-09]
linux-2.6.35.3/Documentation/DocBook/v4l/vbi_hsync.gif

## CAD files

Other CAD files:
SPI_test/no_funcionan/olimexMODTC/MOD-TC/dist/default/production/MOD-TC.production.obj

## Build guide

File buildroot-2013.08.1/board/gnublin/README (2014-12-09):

This the Buildroot support for the LPC3131 based Gnublin board (see here:
http://en.gnublin.org/) and to the Elektor Linux board
(http://www.elektor.com/news/elektor-presents-embedded-linux-made-easy.2147294.
lynkx)

Unfortunately currently the AD and the pwm modules are not supported, i'm about
to add also those drivers as well to the current kernel later.

Base kernel version: 3.7 (available here:
https://gitorious.org/linux-3-7-gnublin/linux-3-7-gnublin/commits/gnublin-
support)

U-boot version: 2009.11 (available here:
https://gitorious.org/u-boot-gnublin-support/u-boot-gnublin-support)

Steps to create a bootable SD card (with the given config you need an at least
500 MB SD card):

1.Config buildroot with the gnublin_defconfig:

$ make gnublin_defconfig

2.Tweak the config for your needs:

$ make menuconfig

3.Build:

$ make

4.Create two partitions on your SD card, one with type of BootIt (fdisk ID: df),
the size should be around 1M, and another partition with all of the left space
on the card, and with the type of normal DOS partition.

5.From the output/images directory dump the u-boot image to the BootIt partition
(probably you have to modify the output /dev files according to your system):

$ dd if=output/images/u-boot.bin of=/dev/sdc1

6.Dump the root fs image as well:

$ dd if=output/images/rootfs.ext2 of=/dev/sdc2

7.Insert the SD card into the board's slot, and your board should boot up with
your newly created system.

Any feedback/report is welcome on the mr.zoltan.gyarmati[at]gmail.com

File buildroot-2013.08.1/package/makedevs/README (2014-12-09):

When building a target filesystem, it is desirable to not have to
become root and then run 'mknod' a thousand times.  Using a device
table you can create device nodes and directories "on the fly".

You can do all sorts of interesting things with a device table file.
For example, if you want to adjust the permissions on a particular
file you can just add an entry like:

  /sbin/foobar        f       2755    0       0       -       -       -       -       -

and (assuming the file /sbin/foobar exists) it will be made setuid
root (regardless of what its permissions are on the host filesystem.

Furthermore, you can use a single table entry to create a many device
minors.  For example, if I wanted to create /dev/hda and
/dev/hda[0-15] I could just use the following two table entries:

  /dev/hda    b       640     0       0       3       0       0       0       -
  /dev/hda    b       640     0       0       3       1       1       1       15

Device table entries take the form of:

<name>    <type>      <mode>  <uid>   <gid>   <major> <minor> <start> <inc>   <count>

where name is the file name,  type can be one of:

      f       A regular file
      d       Directory
      c       Character special device file
      b       Block special device file
      p       Fifo (named pipe)

uid is the user id for the target file, gid is the group id for the
target file.  The rest of the entries (major, minor, etc) apply only
to device special files.

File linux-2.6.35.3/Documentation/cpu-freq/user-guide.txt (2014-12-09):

     CPU frequency and voltage scaling code in the Linux(TM) kernel

		         L i n u x    C P U F r e q

			     U S E R   G U I D E

		    Dominik Brodowski  <linux@brodo.de>

   Clock scaling allows you to change the clock speed of the CPUs on the
    fly. This is a nice method to save battery power, because the lower
            the clock speed, the less power the CPU consumes.

Contents:
---------
1. Supported Architectures and Processors
1.1 ARM
1.2 x86
1.3 sparc64
1.4 ppc
1.5 SuperH
1.6 Blackfin

2. "Policy" / "Governor"?
2.1 Policy
2.2 Governor

3. How to change the CPU cpufreq policy and/or speed
3.1 Preferred interface: sysfs

1. Supported Architectures and Processors
=========================================

1.1 ARM
-------

The following ARM processors are supported by cpufreq:

ARM Integrator
ARM-SA1100
ARM-SA1110
Intel PXA

1.2 x86
-------

The following processors for the x86 architecture are supported by cpufreq:

AMD Elan - SC400, SC410
AMD mobile K6-2+
AMD mobile K6-3+
AMD mobile Duron
AMD mobile Athlon
AMD Opteron
AMD Athlon 64
Cyrix Media GXm
Intel mobile PIII and Intel mobile PIII-M on certain chipsets
Intel Pentium 4, Intel Xeon
Intel Pentium M (Centrino)
National Semiconductors Geode GX
Transmeta Crusoe
Transmeta Efficeon
VIA Cyrix 3 / C3
various processors on some ACPI 2.0-compatible systems [*]

[*] Only if "ACPI Processor Performance States" are available
to the ACPI<->BIOS interface.

1.3 sparc64
-----------

The following processors for the sparc64 architecture are supported by
cpufreq:

UltraSPARC-III

1.4 ppc
-------

Several "PowerBook" and "iBook2" notebooks are supported.

1.5 SuperH
----------

All SuperH processors supporting rate rounding through the clock
framework are supported by cpufreq.

1.6 Blackfin
------------

The following Blackfin processors are supported by cpufreq:

BF522, BF523, BF524, BF525, BF526, BF527, Rev 0.1 or higher
BF531, BF532, BF533, Rev 0.3 or higher
BF534, BF536, BF537, Rev 0.2 or higher
BF561, Rev 0.3 or higher
BF542, BF544, BF547, BF548, BF549, Rev 0.1 or higher

2. "Policy" / "Governor" ?
==========================

Some CPU frequency scaling-capable processor switch between various
frequencies and operating voltages "on the fly" without any kernel or
user involvement. This guarantees very fast switching to a frequency
which is high enough to serve the user's needs, but low enough to save
power.

2.1 Policy
----------

On these systems, all you can do is select the lower and upper
frequency limit as well as whether you want more aggressive
power-saving or more instantly available processing power.

2.2 Governor
------------

On all other cpufreq implementations, these boundaries still need to
be set. Then, a "governor" must be selected. Such a "governor" decides
what speed the processor shall run within the boundaries. One such
"governor" is the "userspace" governor. This one allows the user - or
a yet-to-implement userspace program - to decide what specific speed
the processor shall run at.

3. How to change the CPU cpufreq policy and/or speed
====================================================

3.1 Preferred Interface: sysfs
------------------------------

The preferred interface is located in the sysfs filesystem. If you
mounted it at /sys, the cpufreq interface is located in a subdirectory
"cpufreq" within the cpu-device directory
(e.g. /sys/devices/system/cpu/cpu0/cpufreq/ for the first CPU).

cpuinfo_min_freq :		this file shows the minimum operating
				frequency the processor can run at(in kHz) 
cpuinfo_max_freq :		this file shows the maximum operating
				frequency the processor can run at(in kHz) 
cpuinfo_transition_latency	The time it takes on this CPU to
				switch between two frequencies in nano
				seconds. If unknown or known to be
				that high that the driver does not
				work with the ondemand governor, -1
				(CPUFREQ_ETERNAL) will be returned.
				Using this information can be useful
				to choose an appropriate polling
				frequency for a kernel governor or
				userspace daemon. Make sure to not
				switch the frequency too often
				resulting in performance loss.
scaling_driver :		this file shows what cpufreq driver is
				used to set the frequency on this CPU

scaling_available_governors :	this file shows the CPUfreq governors
				available in this kernel. You can see the
				currently activated governor in

scaling_governor,		and by "echoing" the name of another
				governor you can change it. Please note
				that some governors won't load - they only
				work on some specific architectures or
				processors.

cpuinfo_cur_freq :		Current frequency of the CPU as obtained from
				the hardware, in KHz. This is the frequency
				the CPU actually runs at.

scaling_available_frequencies : List of available frequencies, in KHz.

scaling_min_freq and
scaling_max_freq		show the current "policy limits" (in
				kHz). By echoing new values into these
				files, you can change these limits.
				NOTE: when setting a policy you need to
				first set scaling_max_freq, then
				scaling_min_freq.

affected_cpus :			List of CPUs that require software coordination
				of frequency.

related_cpus :			List of CPUs that need some sort of frequency
				coordination, whether software or hardware.

scaling_driver :		Hardware driver for cpufreq.

scaling_cur_freq :		Current frequency of the CPU as determined by
				the governor and cpufreq core, in KHz. This is
				the frequency the kernel thinks the CPU runs
				at.

bios_limit :			If the BIOS tells the OS to limit a CPU to
				lower frequencies, the user can read out the
				maximum available frequency from this file.
				This typically can happen through (often not
				intended) BIOS settings, restrictions
				triggered through a service processor or other
				BIOS/HW based implementations.
				This does not cover thermal ACPI limitations
				which can be detected through the generic
				thermal driver.

If you have selected the "userspace" governor which allows you to
set the CPU operating frequency to a specific value, you can read out
the current frequency in

scaling_setspeed.		By "echoing" a new frequency into this
				you can change the speed of the CPU,
				but only within the limits of
				scaling_min_freq and scaling_max_freq.

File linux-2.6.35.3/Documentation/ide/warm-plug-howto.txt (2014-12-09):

IDE warm-plug HOWTO
===================

To warm-plug devices on a port 'idex':

# echo -n "1" > /sys/class/ide_port/idex/delete_devices

unplug old device(s) and plug new device(s)

# echo -n "1" > /sys/class/ide_port/idex/scan

done

NOTE: please make sure that partitions are unmounted and that there are
no other active references to devices before doing "delete_devices" step,
also do not attempt "scan" step on devices currently in use -- otherwise
results may be unpredictable and lead to data loss if you're unlucky

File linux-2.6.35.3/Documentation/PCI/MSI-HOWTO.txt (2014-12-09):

		The MSI Driver Guide HOWTO
	Tom L Nguyen tom.l.nguyen@intel.com
			10/03/2003
	Revised Feb 12, 2004 by Martine Silbermann
		email: Martine.Silbermann@hp.com
	Revised Jun 25, 2004 by Tom L Nguyen
	Revised Jul  9, 2008 by Matthew Wilcox <willy@linux.intel.com>
		Copyright 2003, 2008 Intel Corporation

1. About this guide

This guide describes the basics of Message Signaled Interrupts (MSIs),
the advantages of using MSI over traditional interrupt mechanisms, how
to change your driver to use MSI or MSI-X and some basic diagnostics to
try if a device doesn't support MSIs.

2. What are MSIs?

A Message Signaled Interrupt is a write from the device to a special
address which causes an interrupt to be received by the CPU.

The MSI capability was first specified in PCI 2.2 and was later enhanced
in PCI 3.0 to allow each interrupt to be masked individually.  The MSI-X
capability was also introduced with PCI 3.0.  It supports more interrupts
per device than MSI and allows interrupts to be independently configured.

Devices may support both MSI and MSI-X, but only one can be enabled at
a time.

3. Why use MSIs?

There are three reasons why using MSIs can give an advantage over
traditional pin-based interrupts.

Pin-based PCI interrupts are often shared amongst several devices.
To support this, the kernel must call each interrupt handler associated
with an interrupt, which leads to reduced performance for the system as
a whole.  MSIs are never shared, so this problem cannot arise.

When a device writes data to memory, then raises a pin-based interrupt,
it is possible that the interrupt may arrive before all the data has
arrived in memory (this becomes more likely with devices behind PCI-PCI
bridges).  In order to ensure that all the data has arrived in memory,
the interrupt handler must read a register on the device which raised
the interrupt.  PCI transaction ordering rules require that all the data
arrives in memory before the value can be returned from the register.
Using MSIs avoids this problem as the interrupt-generating write cannot
pass the data writes, so by the time the interrupt is raised, the driver
knows that all the data has arrived in memory.

PCI devices can only support a single pin-based interrupt per function.
Often drivers have to query the device to find out what event has
occurred, slowing down interrupt handling for the common case.  With
MSIs, a device can support more interrupts, allowing each interrupt
to be specialised to a different purpose.  One possible design gives
infrequent conditions (such as errors) their own interrupt which allows
the driver to handle the normal interrupt handling path more efficiently.
Other possible designs include giving one interrupt to each packet queue
in a network card or each port in a storage controller.

4. How to use MSIs

PCI devices are initialised to use pin-based interrupts.  The device
driver has to set up the device to use MSI or MSI-X.  Not all machines
support MSIs correctly, and for those machines, the APIs described below
will simply fail and the device will continue to use pin-based interrupts.

4.1 Include kernel support for MSIs

To support MSI or MSI-X, the kernel must be built with the CONFIG_PCI_MSI
option enabled.  This option is only available on some architectures,
and it may depend on some other options also being set.  For example,
on x86, you must also enable X86_UP_APIC or SMP in order to see the
CONFIG_PCI_MSI option.

4.2 Using MSI

Most of the hard work is done for the driver in the PCI layer.  It simply
has to request that the PCI layer set up the MSI capability for this
device.

4.2.1 pci_enable_msi

int pci_enable_msi(struct pci_dev *dev)

A successful call will allocate ONE interrupt to the device, regardless
of how many MSIs the device supports.  The device will be switched from
pin-based interrupt mode to MSI mode.  The dev->irq number is changed
to a new number which represents the message signaled interrupt.
This function should be called before the driver calls request_irq()
since enabling MSIs disables the pin-based IRQ and the driver will not
receive interrupts on the old interrupt.

4.2.2 pci_enable_msi_block

int pci_enable_msi_block(struct pci_dev *dev, int count)

This variation on the above call allows a device driver to request multiple
MSIs.  The MSI specification only allows interrupts to be allocated in
powers of two, up to a maximum of 2^5 (32).

If this function returns 0, it has succeeded in allocating at least as many
interrupts as the driver requested (it may have allocated more in order
to satisfy the power-of-two requirement).  In this case, the function
enables MSI on this device and updates dev->irq to be the lowest of
the new interrupts assigned to it.  The other interrupts assigned to
the device are in the range dev->irq to dev->irq + count - 1.

If this function returns a negative number, it indicates an error and
the driver should not attempt to request any more MSI interrupts for
this device.  If this function returns a positive number, it will be
less than 'count' and indicate the number of interrupts that could have
been allocated.  In neither case will the irq value have been
updated, nor will the device have been switched into MSI mode.

The device driver must decide what action to take if
pci_enable_msi_block() returns a value less than the number asked for.
Some devices can make use of fewer interrupts than the maximum they
request; in this case the driver should call pci_enable_msi_block()
again.  Note that it is not guaranteed to succeed, even when the
'count' has been reduced to the value returned from a previous call to
pci_enable_msi_block().  This is because there are multiple constraints
on the number of vectors that can be allocated; pci_enable_msi_block()
will return as soon as it finds any constraint that doesn't allow the
call to succeed.

4.2.3 pci_disable_msi

void pci_disable_msi(struct pci_dev *dev)

This function should be used to undo the effect of pci_enable_msi() or
pci_enable_msi_block().  Calling it restores dev->irq to the pin-based
interrupt number and frees the previously allocated message signaled
interrupt(s).  The interrupt may subsequently be assigned to another
device, so drivers should not cache the value of dev->irq.

A device driver must always call free_irq() on the interrupt(s)
for which it has called request_irq() before calling this function.
Failure to do so will result in a BUG_ON(), the device will be left with
MSI enabled and will leak its vector.

4.3 Using MSI-X

The MSI-X capability is much more flexible than the MSI capability.
It supports up to 2048 interrupts, each of which can be controlled
independently.  To support this flexibility, drivers must use an array of
`struct msix_entry':

struct msix_entry {
	u16 	vector; /* kernel uses to write alloc vector */
	u16	entry; /* driver uses to specify entry */
};

This allows for the device to use these interrupts in a sparse fashion;
for example it could use interrupts 3 and 1027 and allocate only a
two-element array.  The driver is expected to fill in the 'entry' value
in each element of the array to indicate which entries it wants the kernel
to assign interrupts for.  It is invalid to fill in two entries with the
same number.

4.3.1 pci_enable_msix

int pci_enable_msix(struct pci_dev *dev, struct msix_entry *entries, int nvec)

Calling this function asks the PCI subsystem to allocate 'nvec' MSIs.
The 'entries' argument is a pointer to an array of msix_entry structs
which should be at least 'nvec' entries in size.  On success, the
function will return 0 and the device will have been switched into
MSI-X interrupt mode.  The 'vector' elements in each entry will have
been filled in with the interrupt number.  The driver should then call
request_irq() for each 'vector' that it decides to use.

If this function returns a negative number, it indicates an error and
the driver should not attempt to allocate any more MSI-X interrupts for
this device.  If it returns a positive number, it indicates the maximum
number of interrupt vectors that could have been allocated. See example
below.

This function, in contrast with pci_enable_msi(), does not adjust
dev->irq.  The device will not generate interrupts for this interrupt
number once MSI-X is enabled.  The device driver is responsible for
keeping track of the interrupts assigned to the MSI-X vectors so it can
free them again later.

Device drivers should normally call this function once per device
during the initialization phase.

It is ideal if drivers can cope with a variable number of MSI-X interrupts,
there are many reasons why the platform may not be able to provide the
exact number a driver asks for.

A request loop to achieve that might look like:

static int foo_driver_enable_msix(struct foo_adapter *adapter, int nvec)
{
	while (nvec >= FOO_DRIVER_MINIMUM_NVEC) {
		rc = pci_enable_msix(adapter->pdev,
				     adapter->msix_entries, nvec);
		if (rc > 0)
			nvec = rc;
		else
			return rc;
	}

	return -ENOSPC;
}

4.3.2 pci_disable_msix

void pci_disable_msix(struct pci_dev *dev)

This API should be used to undo the effect of pci_enable_msix().  It frees
the previously allocated message signaled interrupts.  The interrupts may
subsequently be assigned to another device, so drivers should not cache
the value of the 'vector' elements over a call to pci_disable_msix().

A device driver must always call free_irq() on the interrupt(s)
for which it has called request_irq() before calling this function.
Failure to do so will result in a BUG_ON(), the device will be left with
MSI enabled and will leak its vector.

4.3.3 The MSI-X Table

The MSI-X capability specifies a BAR and offset within that BAR for the
MSI-X Table.  This address is mapped by the PCI subsystem, and should not
be accessed directly by the device driver.  If the driver wishes to
mask or unmask an interrupt, it should call disable_irq() / enable_irq().

4.4 Handling devices implementing both MSI and MSI-X capabilities

If a device implements both MSI and MSI-X capabilities, it can
run in either MSI mode or MSI-X mode but not both simultaneously.
This is a requirement of the PCI spec, and it is enforced by the
PCI layer.  Calling pci_enable_msi() when MSI-X is already enabled or
pci_enable_msix() when MSI is already enabled will result in an error.
If a device driver wishes to switch between MSI and MSI-X at runtime,
it must first quiesce the device, then switch it back to pin-interrupt
mode, before calling pci_enable_msi() or pci_enable_msix() and resuming
operation.  This is not expected to be a common operation but may be
useful for debugging or testing during development.

4.5 Considerations when using MSIs

4.5.1 Choosing between MSI-X and MSI

If your device supports both MSI-X and MSI capabilities, you should use
the MSI-X facilities in preference to the MSI facilities.  As mentioned
above, MSI-X supports any number of interrupts between 1 and 2048.
In constrast, MSI is restricted to a maximum of 32 interrupts (and
must be a power of two).  In addition, the MSI interrupt vectors must
be allocated consecutively, so the system may not be able to allocate
as many vectors for MSI as it could for MSI-X.  On some platforms, MSI
interrupts must all be targetted at the same set of CPUs whereas MSI-X
interrupts can all be targetted at different CPUs.

4.5.2 Spinlocks

Most device drivers have a per-device spinlock which is taken in the
interrupt handler.  With pin-based interrupts or a single MSI, it is not
necessary to disable interrupts (Linux guarantees the same interrupt will
not be re-entered).  If a device uses multiple interrupts, the driver
must disable interrupts while the lock is held.  If the device sends
a different interrupt, the driver will deadlock trying to recursively
acquire the spinlock.

There are two solutions.  The first is to take the lock with
spin_lock_irqsave() or spin_lock_irq() (see
Documentation/DocBook/kernel-locking).  The second is to specify
IRQF_DISABLED to request_irq() so that the kernel runs the entire
interrupt routine with interrupts disabled.

If your MSI interrupt routine does not hold the lock for the whole time
it is running, the first solution may be best.  The second solution is
normally preferred as it avoids making two transitions from interrupt
disabled to enabled and back again.

4.6 How to tell whether MSI/MSI-X is enabled on a device

Using 'lspci -v' (as root) may show some devices with "MSI", "Message
Signalled Interrupts" or "MSI-X" capabilities.  Each of these capabilities
has an 'Enable' flag which will be followed with either "+" (enabled)
or "-" (disabled).

5. MSI quirks

Several PCI chipsets or devices are known not to support MSIs.
The PCI stack provides three ways to disable MSIs:

1. globally
2. on all devices behind a specific bridge
3. on a single device

5.1. Disabling MSIs globally

Some host chipsets simply don't support MSIs properly.  If we're
lucky, the manufacturer knows this and has indicated it in the ACPI
FADT table.  In this case, Linux will automatically disable MSIs.
Some boards don't include this information in the table and so we have
to detect them ourselves.  The complete list of these is found near the
quirk_disable_all_msi() function in drivers/pci/quirks.c.

If you have a board which has problems with MSIs, you can pass pci=nomsi
on the kernel command line to disable MSIs on all devices.  It would be
in your best interests to report the problem to linux-pci@vger.kernel.org
including a full 'lspci -v' so we can add the quirks to the kernel.

5.2. Disabling MSIs below a bridge

Some PCI bridges are not able to route MSIs between busses properly.
In this case, MSIs must be disabled on all devices behind the bridge.

Some bridges allow you to enable MSIs by changing some bits in their
PCI configuration space (especially the Hypertransport chipsets such
as the nVidia nForce and Serverworks HT2000).  As with host chipsets,
Linux mostly knows about them and automatically enables MSIs if it can.
If you have a bridge which Linux doesn't yet know about, you can enable
MSIs in configuration space using whatever method you know works, then
enable MSIs on that bridge by doing:

       echo 1 > /sys/bus/pci/devices/$bridge/msi_bus

where $bridge is the PCI address of the bridge you've enabled (eg
0000:00:0e.0).

To disable MSIs, echo 0 instead of 1.  Changing this value should be
done with caution as it can break interrupt handling for all devices
below this bridge.

Again, please notify linux-pci@vger.kernel.org of any bridges that need
special handling.

5.3. Disabling MSIs on a single device

Some devices are known to have faulty MSI implementations.  Usually this
is handled in the individual device driver but occasionally it's necessary
to handle this with a quirk.  Some drivers have an option to disable use
of MSI.  While this is a convenient workaround for the driver author,
it is not good practise, and should not be emulated.

5.4. Finding why MSIs are disabled on a device

From the above three sections, you can see that there are many reasons
why MSIs may not be enabled for a given device.  Your first step should
be to examine your dmesg carefully to determine whether MSIs are enabled
for your machine.  You should also check your .config to be sure you
have enabled CONFIG_PCI_MSI.

Then, 'lspci -t' gives the list of bridges above a device.  Reading
/sys/bus/pci/devices/*/msi_bus will tell you whether MSI are enabled (1)
or disabled (0).  If 0 is found in any of the msi_bus files belonging
to bridges between the PCI root and the device, MSIs are disabled.

It is also worth checking the device driver to see whether it supports MSIs.
For example, it may contain calls to pci_enable_msi(), pci_enable_msix() or
pci_enable_msi_block().

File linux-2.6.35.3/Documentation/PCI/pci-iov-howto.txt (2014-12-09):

		PCI Express I/O Virtualization Howto
		Copyright (C) 2009 Intel Corporation
		    Yu Zhao <yu.zhao@intel.com>

1. Overview

1.1 What is SR-IOV

Single Root I/O Virtualization (SR-IOV) is a PCI Express Extended
capability which makes one physical device appear as multiple virtual
devices. The physical device is referred to as Physical Function (PF)
while the virtual devices are referred to as Virtual Functions (VF).
Allocation of the VF can be dynamically controlled by the PF via
registers encapsulated in the capability. By default, this feature is
not enabled and the PF behaves as traditional PCIe device. Once it's
turned on, each VF's PCI configuration space can be accessed by its own
Bus, Device and Function Number (Routing ID). And each VF also has PCI
Memory Space, which is used to map its register set. VF device driver
operates on the register set so it can be functional and appear as a
real existing PCI device.

2. User Guide

2.1 How can I enable SR-IOV capability

The device driver (PF driver) will control the enabling and disabling
of the capability via API provided by SR-IOV core. If the hardware
has SR-IOV capability, loading its PF driver would enable it and all
VFs associated with the PF.

2.2 How can I use the Virtual Functions

The VF is treated as hot-plugged PCI devices in the kernel, so they
should be able to work in the same way as real PCI devices. The VF
requires device driver that is same as a normal PCI device's.

3. Developer Guide

3.1 SR-IOV API

To enable SR-IOV capability:
	int pci_enable_sriov(struct pci_dev *dev, int nr_virtfn);
	'nr_virtfn' is number of VFs to be enabled.

To disable SR-IOV capability:
	void pci_disable_sriov(struct pci_dev *dev);

To notify SR-IOV core of Virtual Function Migration:
	irqreturn_t pci_sriov_migration(struct pci_dev *dev);

3.2 Usage example

Following piece of code illustrates the usage of the SR-IOV API.

static int __devinit dev_probe(struct pci_dev *dev, const struct pci_device_id *id)
{
	pci_enable_sriov(dev, NR_VIRTFN);

	...

	return 0;
}

static void __devexit dev_remove(struct pci_dev *dev)
{
	pci_disable_sriov(dev);

	...
}

static int dev_suspend(struct pci_dev *dev, pm_message_t state)
{
	...

	return 0;
}

static int dev_resume(struct pci_dev *dev)
{
	...

	return 0;
}

static void dev_shutdown(struct pci_dev *dev)
{
	...
}

static struct pci_driver dev_driver = {
	.name =		"SR-IOV Physical Function driver",
	.id_table =	dev_id_table,
	.probe =	dev_probe,
	.remove =	__devexit_p(dev_remove),
	.suspend =	dev_suspend,
	.resume =	dev_resume,
	.shutdown =	dev_shutdown,
};

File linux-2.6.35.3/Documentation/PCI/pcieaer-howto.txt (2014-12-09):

   The PCI Express Advanced Error Reporting Driver Guide HOWTO
		T. Long Nguyen	<tom.l.nguyen@intel.com>
		Yanmin Zhang	<yanmin.zhang@intel.com>
				07/29/2006

1. Overview

1.1 About this guide

This guide describes the basics of the PCI Express Advanced Error
Reporting (AER) driver and provides information on how to use it, as
well as how to enable the drivers of endpoint devices to conform with
PCI Express AER driver.

1.2 Copyright (C) Intel Corporation 2006.

1.3 What is the PCI Express AER Driver?

PCI Express error signaling can occur on the PCI Express link itself
or on behalf of transactions initiated on the link. PCI Express
defines two error reporting paradigms: the baseline capability and
the Advanced Error Reporting capability. The baseline capability is
required of all PCI Express components providing a minimum defined
set of error reporting requirements. Advanced Error Reporting
capability is implemented with a PCI Express advanced error reporting
extended capability structure providing more robust error reporting.

The PCI Express AER driver provides the infrastructure to support PCI
Express Advanced Error Reporting capability. The PCI Express AER
driver provides three basic functions:

-	Gathers the comprehensive error information if errors occurred.
-	Reports error to the users.
-	Performs error recovery actions.

AER driver only attaches root ports which support PCI-Express AER
capability.

2. User Guide

2.1 Include the PCI Express AER Root Driver into the Linux Kernel

The PCI Express AER Root driver is a Root Port service driver attached
to the PCI Express Port Bus driver. If a user wants to use it, the driver
has to be compiled. Option CONFIG_PCIEAER supports this capability. It
depends on CONFIG_PCIEPORTBUS, so pls. set CONFIG_PCIEPORTBUS=y and
CONFIG_PCIEAER = y.

2.2 Load PCI Express AER Root Driver
There is a case where a system has AER support in BIOS. Enabling the AER
Root driver and having AER support in BIOS may result unpredictable
behavior. To avoid this conflict, a successful load of the AER Root driver
requires ACPI _OSC support in the BIOS to allow the AER Root driver to
request for native control of AER. See the PCI FW 3.0 Specification for
details regarding OSC usage. Currently, lots of firmwares don't provide
_OSC support while they use PCI Express. To support such firmwares,
forceload, a parameter of type bool, could enable AER to continue to
be initiated although firmwares have no _OSC support. To enable the
walkaround, pls. add aerdriver.forceload=y to kernel boot parameter line
when booting kernel. Note that forceload=n by default.

nosourceid, another parameter of type bool, can be used when broken
hardware (mostly chipsets) has root ports that cannot obtain the reporting
source ID. nosourceid=n by default.

2.3 AER error output
When a PCI-E AER error is captured, an error message will be outputed to
console. If it's a correctable error, it is outputed as a warning.
Otherwise, it is printed as an error. So users could choose different
log level to filter out correctable error messages.

Below shows an example:
0000:50:00.0: PCIe Bus Error: severity=Uncorrected (Fatal), type=Transaction Layer, id=0500(Requester ID)
0000:50:00.0:   device [8086:0329] error status/mask=00100000/00000000
0000:50:00.0:    [20] Unsupported Request    (First)
0000:50:00.0:   TLP Header: 04000001 00200a03 05010000 00050100

In the example, 'Requester ID' means the ID of the device who sends
the error message to root port. Pls. refer to pci express specs for
other fields.

3. Developer Guide

To enable AER aware support requires a software driver to configure
the AER capability structure within its device and to provide callbacks.

To support AER better, developers need understand how AER does work
firstly.

PCI Express errors are classified into two types: correctable errors
and uncorrectable errors. This classification is based on the impacts
of those errors, which may result in degraded performance or function
failure.

Correctable errors pose no impacts on the functionality of the
interface. The PCI Express protocol can recover without any software
intervention or any loss of data. These errors are detected and
corrected by hardware. Unlike correctable errors, uncorrectable
errors impact functionality of the interface. Uncorrectable errors
can cause a particular transaction or a particular PCI Express link
to be unreliable. Depending on those error conditions, uncorrectable
errors are further classified into non-fatal errors and fatal errors.
Non-fatal errors cause the particular transaction to be unreliable,
but the PCI Express link itself is fully functional. Fatal errors, on
the other hand, cause the link to be unreliable.

When AER is enabled, a PCI Express device will automatically send an
error message to the PCIe root port above it when the device captures
an error. The Root Port, upon receiving an error reporting message,
internally processes and logs the error message in its PCI Express
capability structure. Error information being logged includes storing
the error reporting agent's requestor ID into the Error Source
Identification Registers and setting the error bits of the Root Error
Status Register accordingly. If AER error reporting is enabled in Root
Error Command Register, the Root Port generates an interrupt if an
error is detected.

Note that the errors as described above are related to the PCI Express
hierarchy and links. These errors do not include any device specific
errors because device specific errors will still get sent directly to
the device driver.

3.1 Configure the AER capability structure

AER aware drivers of PCI Express component need change the device
control registers to enable AER. They also could change AER registers,
including mask and severity registers. Helper function
pci_enable_pcie_error_reporting could be used to enable AER. See
section 3.3.

3.2. Provide callbacks

3.2.1 callback reset_link to reset pci express link

This callback is used to reset the pci express physical link when a
fatal error happens. The root port aer service driver provides a
default reset_link function, but different upstream ports might
have different specifications to reset pci express link, so all
upstream ports should provide their own reset_link functions.

In struct pcie_port_service_driver, a new pointer, reset_link, is
added.

pci_ers_result_t (*reset_link) (struct pci_dev *dev);

Section 3.2.2.2 provides more detailed info on when to call
reset_link.

3.2.2 PCI error-recovery callbacks

The PCI Express AER Root driver uses error callbacks to coordinate
with downstream device drivers associated with a hierarchy in question
when performing error recovery actions.

Data struct pci_driver has a pointer, err_handler, to point to
pci_error_handlers who consists of a couple of callback function
pointers. AER driver follows the rules defined in
pci-error-recovery.txt except pci express specific parts (e.g.
reset_link). Pls. refer to pci-error-recovery.txt for detailed
definitions of the callbacks.

Below sections specify when to call the error callback functions.

3.2.2.1 Correctable errors

Correctable errors pose no impacts on the functionality of
the interface. The PCI Express protocol can recover without any
software intervention or any loss of data. These errors do not
require any recovery actions. The AER driver clears the device's
correctable error status register accordingly and logs these errors.

3.2.2.2 Non-correctable (non-fatal and fatal) errors

If an error message indicates a non-fatal error, performing link reset
at upstream is not required. The AER driver calls error_detected(dev,
pci_channel_io_normal) to all drivers associated within a hierarchy in
question. for example,
EndPoint<==>DownstreamPort B<==>UpstreamPort A<==>RootPort.
If Upstream port A captures an AER error, the hierarchy consists of
Downstream port B and EndPoint.

A driver may return PCI_ERS_RESULT_CAN_RECOVER,
PCI_ERS_RESULT_DISCONNECT, or PCI_ERS_RESULT_NEED_RESET, depending on
whether it can recover or the AER driver calls mmio_enabled as next.

If an error message indicates a fatal error, kernel will broadcast
error_detected(dev, pci_channel_io_frozen) to all drivers within
a hierarchy in question. Then, performing link reset at upstream is
necessary. As different kinds of devices might use different approaches
to reset link, AER port service driver is required to provide the
function to reset link. Firstly, kernel looks for if the upstream
component has an aer driver. If it has, kernel uses the reset_link
callback of the aer driver. If the upstream component has no aer driver
and the port is downstream port, we will perform a hot reset as the
default by setting the Secondary Bus Reset bit of the Bridge Control
register associated with the downstream port. As for upstream ports,
they should provide their own aer service drivers with reset_link
function. If error_detected returns PCI_ERS_RESULT_CAN_RECOVER and
reset_link returns PCI_ERS_RESULT_RECOVERED, the error handling goes
to mmio_enabled.

3.3 helper functions

3.3.1 int pci_enable_pcie_error_reporting(struct pci_dev *dev);
pci_enable_pcie_error_reporting enables the device to send error
messages to root port when an error is detected. Note that devices
don't enable the error reporting by default, so device drivers need
call this function to enable it.

3.3.2 int pci_disable_pcie_error_reporting(struct pci_dev *dev);
pci_disable_pcie_error_reporting disables the device to send error
messages to root port when an error is detected.

3.3.3 int pci_cleanup_aer_uncorrect_error_status(struct pci_dev *dev);
pci_cleanup_aer_uncorrect_error_status cleanups the uncorrectable
error status register.

3.4 Frequent Asked Questions

Q: What happens if a PCI Express device driver does not provide an
error recovery handler (pci_driver->err_handler is equal to NULL)?

A: The devices attached with the driver won't be recovered. If the
error is fatal, kernel will print out warning messages. Please refer
to section 3 for more information.

Q: What happens if an upstream port service driver does not provide
callback reset_link?

A: Fatal error recovery will fail if the errors are reported by the
upstream ports who are attached by the service driver.

Q: How does this infrastructure deal with driver that is not PCI
Express aware?

A: This infrastructure calls the error callback functions of the
driver when an error happens. But if the driver is not aware of
PCI Express, the device might not report its own errors to root
port.

Q: What modifications will that driver need to make it compatible
with the PCI Express AER Root driver?

A: It could call the helper functions to enable AER in devices and
cleanup uncorrectable status register. Pls. refer to section 3.3.

4. Software error injection

Debugging PCIe AER error recovery code is quite difficult because it
is hard to trigger real hardware errors. Software based error
injection can be used to fake various kinds of PCIe errors.

First you should enable PCIe AER software error injection in kernel
configuration, that is, following item should be in your .config.

CONFIG_PCIEAER_INJECT=y or CONFIG_PCIEAER_INJECT=m

After reboot with new kernel or insert the module, a device file named
/dev/aer_inject should be created.

Then, you need a user space tool named aer-inject, which can be gotten
from:
    http://www.kernel.org/pub/linux/utils/pci/aer-inject/

More information about aer-inject can be found in the document comes
with its source code.

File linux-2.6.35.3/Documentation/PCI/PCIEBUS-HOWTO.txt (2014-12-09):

		The PCI Express Port Bus Driver Guide HOWTO
	Tom L Nguyen tom.l.nguyen@intel.com
			11/03/2004

1. About this guide

This guide describes the basics of the PCI Express Port Bus driver
and provides information on how to enable the service drivers to
register/unregister with the PCI Express Port Bus Driver.

2. Copyright 2004 Intel Corporation

3. What is the PCI Express Port Bus Driver

A PCI Express Port is a logical PCI-PCI Bridge structure. There
are two types of PCI Express Port: the Root Port and the Switch
Port. The Root Port originates a PCI Express link from a PCI Express
Root Complex and the Switch Port connects PCI Express links to
internal logical PCI buses. The Switch Port, which has its secondary
bus representing the switch's internal routing logic, is called the
switch's Upstream Port. The switch's Downstream Port is bridging from
switch's internal routing bus to a bus representing the downstream
PCI Express link from the PCI Express Switch.

A PCI Express Port can provide up to four distinct functions,
referred to in this document as services, depending on its port type.
PCI Express Port's services include native hotplug support (HP),
power management event support (PME), advanced error reporting
support (AER), and virtual channel support (VC). These services may
be handled by a single complex driver or be individually distributed
and handled by corresponding service drivers.

4. Why use the PCI Express Port Bus Driver?

In existing Linux kernels, the Linux Device Driver Model allows a
physical device to be handled by only a single driver. The PCI
Express Port is a PCI-PCI Bridge device with multiple distinct
services. To maintain a clean and simple solution each service
may have its own software service driver. In this case several
service drivers will compete for a single PCI-PCI Bridge device.
For example, if the PCI Express Root Port native hotplug service
driver is loaded first, it claims a PCI-PCI Bridge Root Port. The
kernel therefore does not load other service drivers for that Root
Port. In other words, it is impossible to have multiple service
drivers load and run on a PCI-PCI Bridge device simultaneously
using the current driver model.

To enable multiple service drivers running simultaneously requires
having a PCI Express Port Bus driver, which manages all populated
PCI Express Ports and distributes all provided service requests
to the corresponding service drivers as required. Some key
advantages of using the PCI Express Port Bus driver are listed below:

	- Allow multiple service drivers to run simultaneously on
	  a PCI-PCI Bridge Port device.

	- Allow service drivers implemented in an independent
	  staged approach.

	- Allow one service driver to run on multiple PCI-PCI Bridge
	  Port devices.

	- Manage and distribute resources of a PCI-PCI Bridge Port
	  device to requested service drivers.

5. Configuring the PCI Express Port Bus Driver vs. Service Drivers

5.1 Including the PCI Express Port Bus Driver Support into the Kernel

Including the PCI Express Port Bus driver depends on whether the PCI
Express support is included in the kernel config. The kernel will
automatically include the PCI Express Port Bus driver as a kernel
driver when the PCI Express support is enabled in the kernel.

5.2 Enabling Service Driver Support

PCI device drivers are implemented based on Linux Device Driver Model.
All service drivers are PCI device drivers. As discussed above, it is
impossible to load any service driver once the kernel has loaded the
PCI Express Port Bus Driver. To meet the PCI Express Port Bus Driver
Model requires some minimal changes on existing service drivers that
imposes no impact on the functionality of existing service drivers.

A service driver is required to use the two APIs shown below to
register its service with the PCI Express Port Bus driver (see
section 5.2.1 & 5.2.2). It is important that a service driver
initializes the pcie_port_service_driver data structure, included in
header file /include/linux/pcieport_if.h, before calling these APIs.
Failure to do so will result an identity mismatch, which prevents
the PCI Express Port Bus driver from loading a service driver.

5.2.1 pcie_port_service_register

int pcie_port_service_register(struct pcie_port_service_driver *new)

This API replaces the Linux Driver Model's pci_register_driver API. A
service driver should always calls pcie_port_service_register at
module init. Note that after service driver being loaded, calls
such as pci_enable_device(dev) and pci_set_master(dev) are no longer
necessary since these calls are executed by the PCI Port Bus driver.

5.2.2 pcie_port_service_unregister

void pcie_port_service_unregister(struct pcie_port_service_driver *new)

pcie_port_service_unregister replaces the Linux Driver Model's
pci_unregister_driver. It's always called by service driver when a
module exits.

5.2.3 Sample Code

Below is sample service driver code to initialize the port service
driver data structure.

static struct pcie_port_service_id service_id[] = { {
	.vendor = PCI_ANY_ID,
	.device = PCI_ANY_ID,
	.port_type = PCIE_RC_PORT,
	.service_type = PCIE_PORT_SERVICE_AER,
	}, { /* end: all zeroes */ }
};

static struct pcie_port_service_driver root_aerdrv = {
	.name		= (char *)device_name,
	.id_table	= &service_id[0],

	.probe		= aerdrv_load,
	.remove		= aerdrv_unload,

	.suspend	= aerdrv_suspend,
	.resume		= aerdrv_resume,
};

Below is a sample code for registering/unregistering a service
driver.

static int __init aerdrv_service_init(void)
{
	int retval = 0;

	retval = pcie_port_service_register(&root_aerdrv);
	if (!retval) {
		/*
		 * FIX ME
		 */
	}
	return retval;
}

static void __exit aerdrv_service_exit(void)
{
	pcie_port_service_unregister(&root_aerdrv);
}

module_init(aerdrv_service_init);
module_exit(aerdrv_service_exit);

6. Possible Resource Conflicts

Since all service drivers of a PCI-PCI Bridge Port device are
allowed to run simultaneously, below lists a few of possible resource
conflicts with proposed solutions.

6.1 MSI Vector Resource

The MSI capability structure enables a device software driver to call
pci_enable_msi to request MSI based interrupts. Once MSI interrupts
are enabled on a device, it stays in this mode until a device driver
calls pci_disable_msi to disable MSI interrupts and revert back to
INTx emulation mode. Since service drivers of the same PCI-PCI Bridge
port share the same physical device, if an individual service driver
calls pci_enable_msi/pci_disable_msi it may result unpredictable
behavior. For example, two service drivers run simultaneously on the
same physical Root Port. Both service drivers call pci_enable_msi to
request MSI based interrupts. A service driver may not know whether
any other service drivers have run on this Root Port. If either one
of them calls pci_disable_msi, it puts the other service driver
in a wrong interrupt mode.

To avoid this situation all service drivers are not permitted to
switch interrupt mode on its device. The PCI Express Port Bus driver
is responsible for determining the interrupt mode and this should be
transparent to service drivers. Service drivers need to know only
the vector IRQ assigned to the field irq of struct pcie_device, which
is passed in when the PCI Express Port Bus driver probes each service
driver. Service drivers should use (struct pcie_device*)dev->irq to
call request_irq/free_irq. In addition, the interrupt mode is stored
in the field interrupt_mode of struct pcie_device.

6.2 MSI-X Vector Resources

Similar to the MSI a device driver for an MSI-X capable device can
call pci_enable_msix to request MSI-X interrupts. All service drivers
are not permitted to switch interrupt mode on its device. The PCI
Express Port Bus driver is responsible for determining the interrupt
mode and this should be transparent to service drivers. Any attempt
by service driver to call pci_enable_msix/pci_disable_msix may
result unpredictable behavior. Service drivers should use
(struct pcie_device*)dev->irq and call request_irq/free_irq.

6.3 PCI Memory/IO Mapped Regions

Service drivers for PCI Express Power Management (PME), Advanced
Error Reporting (AER), Hot-Plug (HP) and Virtual Channel (VC) access
PCI configuration space on the PCI Express port. In all cases the
registers accessed are independent of each other. This patch assumes
that all service drivers will be well behaved and not overwrite
other service driver's configuration settings.

6.4 PCI Config Registers

Each service driver runs its PCI config operations on its own
capability structure except the PCI Express capability structure, in
which Root Control register and Device Control register are shared
between PME and AER. This patch assumes that all service drivers
will be well behaved and not overwrite other service driver's
configuration settings.

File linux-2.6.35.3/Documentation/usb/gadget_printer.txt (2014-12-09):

                       Linux USB Printer Gadget Driver
                                 06/04/2007

              Copyright (C) 2007 Craig W. Nadler <craig@nadler.us>

GENERAL
=======

This driver may be used if you are writing printer firmware using Linux as
the embedded OS. This driver has nothing to do with using a printer with
your Linux host system.

You will need a USB device controller and a Linux driver for it that accepts
a gadget / "device class" driver using the Linux USB Gadget API. After the
USB device controller driver is loaded then load the printer gadget driver.
This will present a printer interface to the USB Host that your USB Device
port is connected to.

This driver is structured for printer firmware that runs in user mode. The
user mode printer firmware will read and write data from the kernel mode
printer gadget driver using a device file. The printer returns a printer status
byte when the USB HOST sends a device request to get the printer status.  The
user space firmware can read or write this status byte using a device file
/dev/g_printer . Both blocking and non-blocking read/write calls are supported.

HOWTO USE THIS DRIVER
=====================

To load the USB device controller driver and the printer gadget driver. The
following example uses the Netchip 2280 USB device controller driver:

modprobe net2280
modprobe g_printer

The follow command line parameter can be used when loading the printer gadget
(ex: modprobe g_printer idVendor=0x0525 idProduct=0xa4a8 ):

idVendor - This is the Vendor ID used in the device descriptor. The default is
	the Netchip vendor id 0x0525. YOU MUST CHANGE TO YOUR OWN VENDOR ID
	BEFORE RELEASING A PRODUCT. If you plan to release a product and don't
	already have a Vendor ID please see www.usb.org for details on how to
	get one.

idProduct - This is the Product ID used in the device descriptor. The default
	is 0xa4a8, you should change this to an ID that's not used by any of
	your other USB products if you have any. It would be a good idea to
	start numbering your products starting with say 0x0001.

bcdDevice - This is the version number of your product. It would be a good idea
	to put your firmware version here.

iManufacturer - A string containing the name of the Vendor.

iProduct - A string containing the Product Name.

iSerialNum - A string containing the Serial Number. This should be changed for
	each unit of your product.

iPNPstring -  The PNP ID string used for this printer. You will want to set
	either on the command line or hard code the PNP ID string used for
	your printer product.

qlen - The number of 8k buffers to use per endpoint. The default is 10, you
	should tune this for your product. You may also want to tune the
	size of each buffer for your product.

USING THE EXAMPLE CODE
======================

This example code talks to stdout, instead of a print engine.

To compile the test code below:

1) save it to a file called prn_example.c
2) compile the code with the follow command:
	 gcc prn_example.c -o prn_example

To read printer data from the host to stdout:

	# prn_example -read_data

To write printer data from a file (data_file) to the host:

	# cat data_file | prn_example -write_data

To get the current printer status for the gadget driver:

	# prn_example -get_status

	Printer status is:
	     Printer is NOT Selected
	     Paper is Out
	     Printer OK

To set printer to Selected/On-line:

	# prn_example -selected

To set printer to Not Selected/Off-line:

	# prn_example -not_selected

To set paper status to paper out:

	# prn_example -paper_out

To set paper status to paper loaded:

	# prn_example -paper_loaded

To set error status to printer OK:

	# prn_example -no_error

To set error status to ERROR:

	# prn_example -error

EXAMPLE CODE
============

#include <stdio.h>
#include <stdlib.h>
#include <fcntl.h>
#include <linux/poll.h>
#include <sys/ioctl.h>
#include <linux/usb/g_printer.h>

#define PRINTER_FILE			"/dev/g_printer"
#define BUF_SIZE			512

/*
 * 'usage()' - Show program usage.
 */

static void
usage(const char *option)		/* I - Option string or NULL */
{
	if (option) {
		fprintf(stderr,"prn_example: Unknown option \"%s\"!\n",
				option);
	}

	fputs("\n", stderr);
	fputs("Usage: prn_example -[options]\n", stderr);
	fputs("Options:\n", stderr);
	fputs("\n", stderr);
	fputs("-get_status    Get the current printer status.\n", stderr);
	fputs("-selected      Set the selected status to selected.\n", stderr);
	fputs("-not_selected  Set the selected status to NOT selected.\n",
			stderr);
	fputs("-error         Set the error status to error.\n", stderr);
	fputs("-no_error      Set the error status to NO error.\n", stderr);
	fputs("-paper_out     Set the paper status to paper out.\n", stderr);
	fputs("-paper_loaded  Set the paper status to paper loaded.\n",
			stderr);
	fputs("-read_data     Read printer data from driver.\n", stderr);
	fputs("-write_data    Write printer sata to driver.\n", stderr);
	fputs("-NB_read_data  (Non-Blocking) Read printer data from driver.\n",
			stderr);
	fputs("\n\n", stderr);

	exit(1);
}

static int
read_printer_data()
{
	struct pollfd	fd[1];

	/* Open device file for printer gadget. */
	fd[0].fd = open(PRINTER_FILE, O_RDWR);
	if (fd[0].fd < 0) {
		printf("Error %d opening %s\n", fd[0].fd, PRINTER_FILE);
		close(fd[0].fd);
		return(-1);
	}

	fd[0].events = POLLIN | POLLRDNORM;

	while (1) {
		static char buf[BUF_SIZE];
		int bytes_read;
		int retval;

		/* Wait for up to 1 second for data. */
		retval = poll(fd, 1, 1000);

		if (retval && (fd[0].revents & POLLRDNORM)) {

			/* Read data from printer gadget driver. */
			bytes_read = read(fd[0].fd, buf, BUF_SIZE);

			if (bytes_read < 0) {
				printf("Error %d reading from %s\n",
						fd[0].fd, PRINTER_FILE);
				close(fd[0].fd);
				return(-1);
			} else if (bytes_read > 0) {
				/* Write data to standard OUTPUT (stdout). */
				fwrite(buf, 1, bytes_read, stdout);
				fflush(stdout);
			}

		}

	}

	/* Close the device file. */
	close(fd[0].fd);

	return 0;
}

static int
write_printer_data()
{
	struct pollfd	fd[1];

	/* Open device file for printer gadget. */
	fd[0].fd = open (PRINTER_FILE, O_RDWR);
	if (fd[0].fd < 0) {
		printf("Error %d opening %s\n", fd[0].fd, PRINTER_FILE);
		close(fd[0].fd);
		return(-1);
	}

	fd[0].events = POLLOUT | POLLWRNORM;

	while (1) {
		int retval;
		static char buf[BUF_SIZE];
		/* Read data from standard INPUT (stdin). */
		int bytes_read = fread(buf, 1, BUF_SIZE, stdin);

		if (!bytes_read) {
			break;
		}

		while (bytes_read) {

			/* Wait for up to 1 second to sent data. */
			retval = poll(fd, 1, 1000);

			/* Write data to printer gadget driver. */
			if (retval && (fd[0].revents & POLLWRNORM)) {
				retval = write(fd[0].fd, buf, bytes_read);
				if (retval < 0) {
					printf("Error %d writing to %s\n",
							fd[0].fd,
							PRINTER_FILE);
					close(fd[0].fd);
					return(-1);
				} else {
					bytes_read -= retval;
				}

			}

		}

	}

	/* Wait until the data has been sent. */
	fsync(fd[0].fd);

	/* Close the device file. */
	close(fd[0].fd);

	return 0;
}

static int
read_NB_printer_data()
{
	int		fd;
	static char	buf[BUF_SIZE];
	int		bytes_read;

	/* Open device file for printer gadget. */
	fd = open(PRINTER_FILE, O_RDWR|O_NONBLOCK);
	if (fd < 0) {
		printf("Error %d opening %s\n", fd, PRINTER_FILE);
		close(fd);
		return(-1);
	}

	while (1) {
		/* Read data from printer gadget driver. */
		bytes_read = read(fd, buf, BUF_SIZE);
		if (bytes_read <= 0) {
			break;
		}

		/* Write data to standard OUTPUT (stdout). */
		fwrite(buf, 1, bytes_read, stdout);
		fflush(stdout);
	}

	/* Close the device file. */
	close(fd);

	return 0;
}

static int
get_printer_status()
{
	int	retval;
	int	fd;

	/* Open device file for printer gadget. */
	fd = open(PRINTER_FILE, O_RDWR);
	if (fd < 0) {
		printf("Error %d opening %s\n", fd, PRINTER_FILE);
		close(fd);
		return(-1);
	}

	/* Make the IOCTL call. */
	retval = ioctl(fd, GADGET_GET_PRINTER_STATUS);
	if (retval < 0) {
		fprintf(stderr, "ERROR: Failed to set printer status\n");
		return(-1);
	}

	/* Close the device file. */
	close(fd);

	return(retval);
}

static int
set_printer_status(unsigned char buf, int clear_printer_status_bit)
{
	int	retval;
	int	fd;

	retval = get_printer_status();
	if (retval < 0) {
		fprintf(stderr, "ERROR: Failed to get printer status\n");
		return(-1);
	}

	/* Open device file for printer gadget. */
	fd = open(PRINTER_FILE, O_RDWR);

	if (fd < 0) {
		printf("Error %d opening %s\n", fd, PRINTER_FILE);
		close(fd);
		return(-1);
	}

	if (clear_printer_status_bit) {
		retval &= ~buf;
	} else {
		retval |= buf;
	}

	/* Make the IOCTL call. */
	if (ioctl(fd, GADGET_SET_PRINTER_STATUS, (unsigned char)retval)) {
		fprintf(stderr, "ERROR: Failed to set printer status\n");
		return(-1);
	}

	/* Close the device file. */
	close(fd);

	return 0;
}

static int
display_printer_status()
{
	char	printer_status;

	printer_status = get_printer_status();
	if (printer_status < 0) {
		fprintf(stderr, "ERROR: Failed to get printer status\n");
		return(-1);
	}

	printf("Printer status is:\n");
	if (printer_status & PRINTER_SELECTED) {
		printf("     Printer is Selected\n");
	} else {
		printf("     Printer is NOT Selected\n");
	}
	if (printer_status & PRINTER_PAPER_EMPTY) {
		printf("     Paper is Out\n");
	} else {
		printf("     Paper is Loaded\n");
	}
	if (printer_status & PRINTER_NOT_ERROR) {
		printf("     Printer OK\n");
	} else {
		printf("     Printer ERROR\n");
	}

	return(0);
}

int
main(int  argc, char *argv[])
{
	int	i;		/* Looping var */
	int	retval = 0;

	/* No Args */
	if (argc == 1) {
		usage(0);
		exit(0);
	}

	for (i = 1; i < argc && !retval; i ++) {

		if (argv[i][0] != '-') {
			continue;
		}

		if (!strcmp(argv[i], "-get_status")) {
			if (display_printer_status()) {
				retval = 1;
			}

		} else if (!strcmp(argv[i], "-paper_loaded")) {
			if (set_printer_status(PRINTER_PAPER_EMPTY, 1)) {
				retval = 1;
			}

		} else if (!strcmp(argv[i], "-paper_out")) {
			if (set_printer_status(PRINTER_PAPER_EMPTY, 0)) {
				retval = 1;
			}

		} else if (!strcmp(argv[i], "-selected")) {
			if (set_printer_status(PRINTER_SELECTED, 0)) {
				retval = 1;
			}

		} else if (!strcmp(argv[i], "-not_selected")) {
			if (set_printer_status(PRINTER_SELECTED, 1)) {
				retval = 1;
			}

		} else if (!strcmp(argv[i], "-error")) {
			if (set_printer_status(PRINTER_NOT_ERROR, 1)) {
				retval = 1;
			}

		} else if (!strcmp(argv[i], "-no_error")) {
			if (set_printer_status(PRINTER_NOT_ERROR, 0)) {
				retval = 1;
			}

		} else if (!strcmp(argv[i], "-read_data")) {
			if (read_printer_data()) {
				retval = 1;
			}

		} else if (!strcmp(argv[i], "-write_data")) {
			if (write_printer_data()) {
				retval = 1;
			}

		} else if (!strcmp(argv[i], "-NB_read_data")) {
			if (read_NB_printer_data()) {
				retval = 1;
			}

		} else {
			usage(argv[i]);
			retval = 1;
		}
	}

	exit(retval);
}

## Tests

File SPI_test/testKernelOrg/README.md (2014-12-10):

El archivo que se usó la final es el leerTemp.c
los demas son etapas de ensayo.
el archivo ejecutable que guarda la temperatura en grados Celsius es readTermo, a.out es un ensayo para probar que SPI funciona.

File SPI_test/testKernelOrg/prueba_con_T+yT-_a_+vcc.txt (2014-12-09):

Prueba conectando la entrada de termocupla a +VCC. Salida:

# ./a.out 
spi mode: 0x7a120
bits per word: 8
max speed: 500000 Hz (500 KHz)

2B 95 26 A4 00 00 
00 00 00 00 00 00 
00 00 00 00 00 00 
00 00 00 00 00 00 
00 00 00 00 00 00 
00 00 00 00 00 00 
00 00 
# ./a.out 
spi mode: 0x7a120
bits per word: 8
max speed: 500000 Hz (500 KHz)

2A DD 27 04 00 00 
00 00 00 00 00 00 
00 00 00 00 00 00 
00 00 00 00 00 00 
00 00 00 00 00 00 
00 00 00 00 00 00 
00 00 
# ./a.out 
spi mode: 0x7a120
bits per word: 8
max speed: 500000 Hz (500 KHz)

00 00 00 00 00 00 
00 00 00 00 00 00 
00 00 00 00 00 00 
00 00 00 00 00 00 
00 00 00 00 00 00 
00 00 00 00 00 00 
00 00 
# ./a.out 
spi mode: 0x7a120
bits per word: 8
max speed: 500000 Hz (500 KHz)

2F 31 27 E4 00 00 
00 00 00 00 00 00 
00 00 00 00 00 00 
00 00 00 00 00 00 
00 00 00 00 00 00 
00 00 00 00 00 00 
00 00 
# ./a.out 
spi mode: 0x7a120
bits per word: 8
max speed: 500000 Hz (500 KHz)

2F 99 28 04 00 00 
00 00 00 00 00 00 
00 00 00 00 00 00 
00 00 00 00 00 00 
00 00 00 00 00 00 
00 00 00 00 00 00 
00 00 
# ./a.out 
spi mode: 0x7a120
bits per word: 8
max speed: 500000 Hz (500 KHz)

2F 31 28 24 00 00 
00 00 00 00 00 00 
00 00 00 00 00 00 
00 00 00 00 00 00 
00 00 00 00 00 00 
00 00 00 00 00 00 
00 00 
# ./a.out 
spi mode: 0x7a120
bits per word: 8
max speed: 500000 Hz (500 KHz)

30 45 28 24 00 00 
00 00 00 00 00 00 
00 00 00 00 00 00 
00 00 00 00 00 00 
00 00 00 00 00 00 
00 00 00 00 00 00 
00 00 
# cd /home/
# ./a.out 
spi mode: 0x7a120
bits per word: 8
max speed: 500000 Hz (500 KHz)

31 AD 2A 14 00 00 
00 00 00 00 00 00 
00 00 00 00 00 00 
00 00 00 00 00 00 
00 00 00 00 00 00 
00 00 00 00 00 00 
00 00 
# ./a.out 
spi mode: 0x7a120
bits per word: 8
max speed: 500000 Hz (500 KHz)

30 85 2A 34 00 00 
00 00 00 00 00 00 
00 00 00 00 00 00 
00 00 00 00 00 00 
00 00 00 00 00 00 
00 00 00 00 00 00 
00 00 
# ./a.out 
spi mode: 0x7a120
bits per word: 8
max speed: 500000 Hz (500 KHz)

30 A9 2A 34 00 00 
00 00 00 00 00 00 
00 00 00 00 00 00 
00 00 00 00 00 00 
00 00 00 00 00 00 
00 00 00 00 00 00 
00 00 
# ./a.out 
spi mode: 0x7a120
bits per word: 8
max speed: 500000 Hz (500 KHz)

30 11 2A 64 00 00 
00 00 00 00 00 00 
00 00 00 00 00 00 
00 00 00 00 00 00 
00 00 00 00 00 00 
00 00 00 00 00 00 
00 00 
# ./a.out 
spi mode: 0x7a120
bits per word: 8
max speed: 500000 Hz (500 KHz)

31 0D 2A 64 00 00 
00 00 00 00 00 00 
00 00 00 00 00 00 
00 00 00 00 00 00 
00 00 00 00 00 00 
00 00 00 00 00 00 
00 00

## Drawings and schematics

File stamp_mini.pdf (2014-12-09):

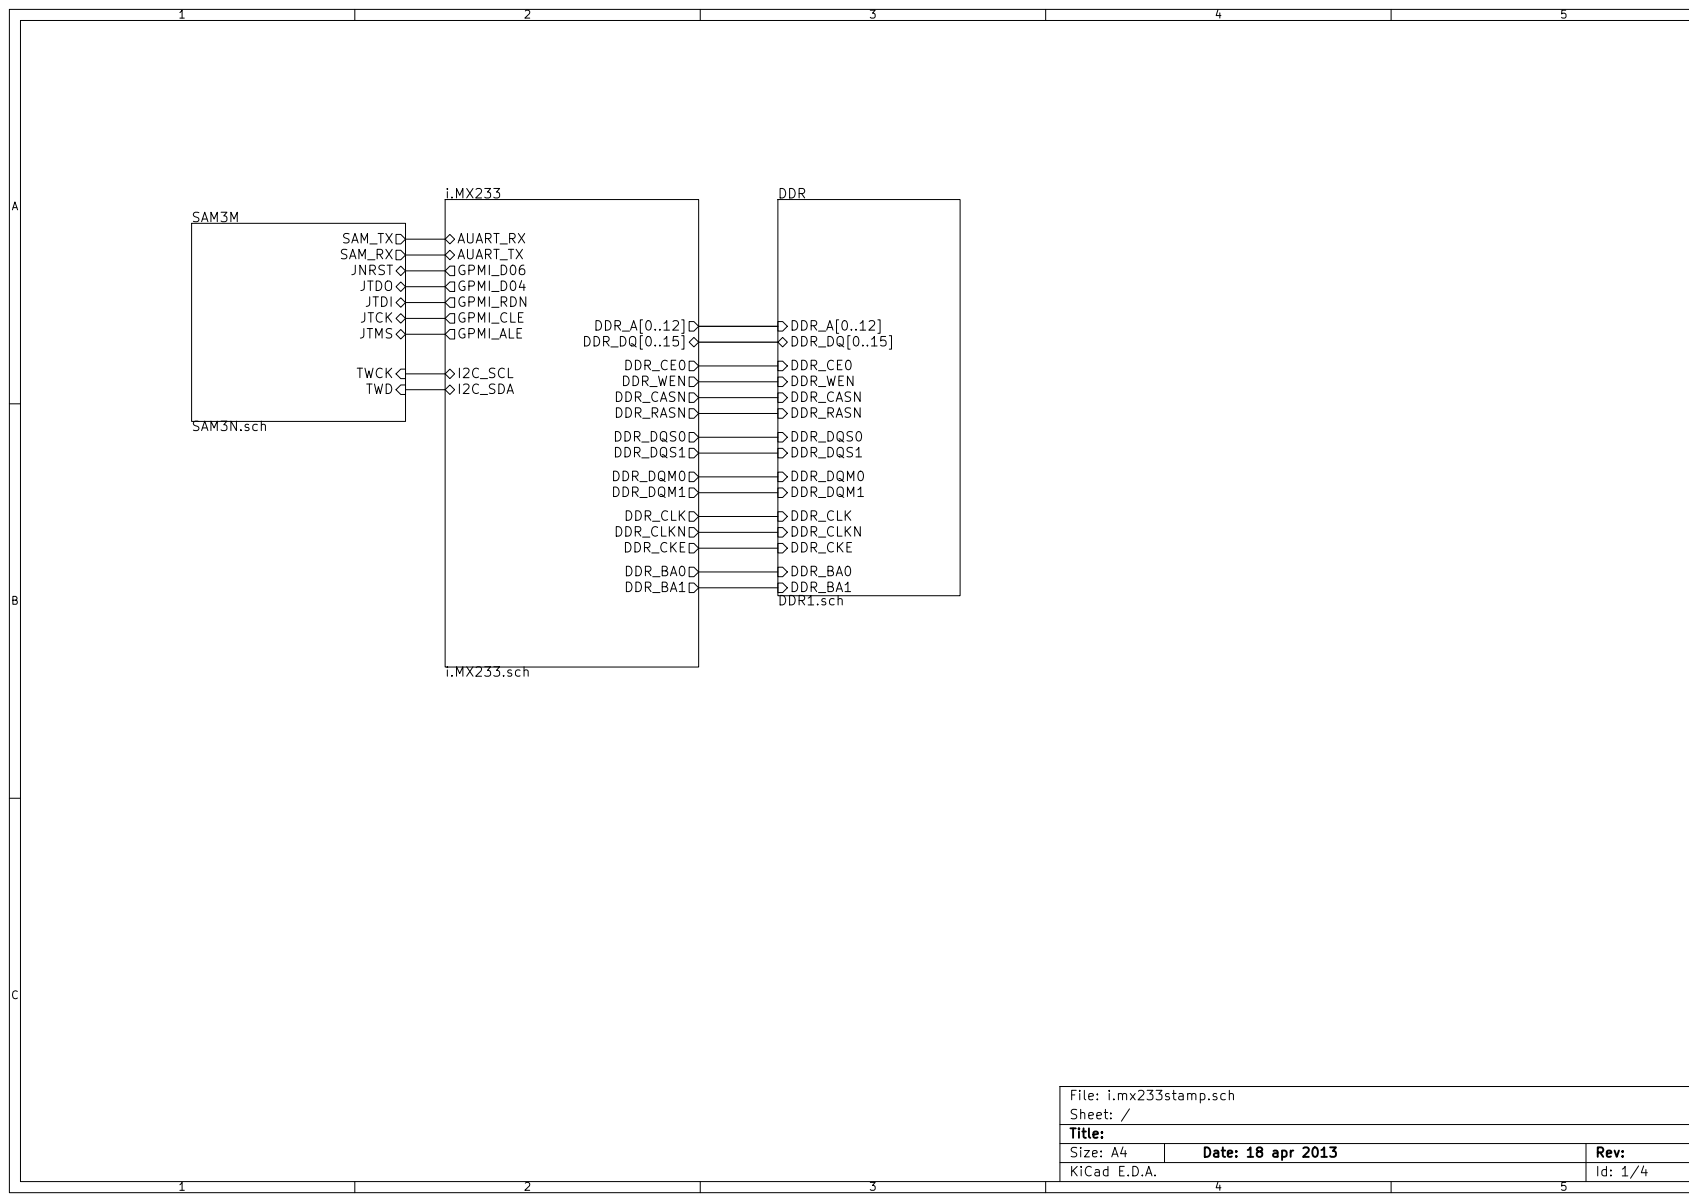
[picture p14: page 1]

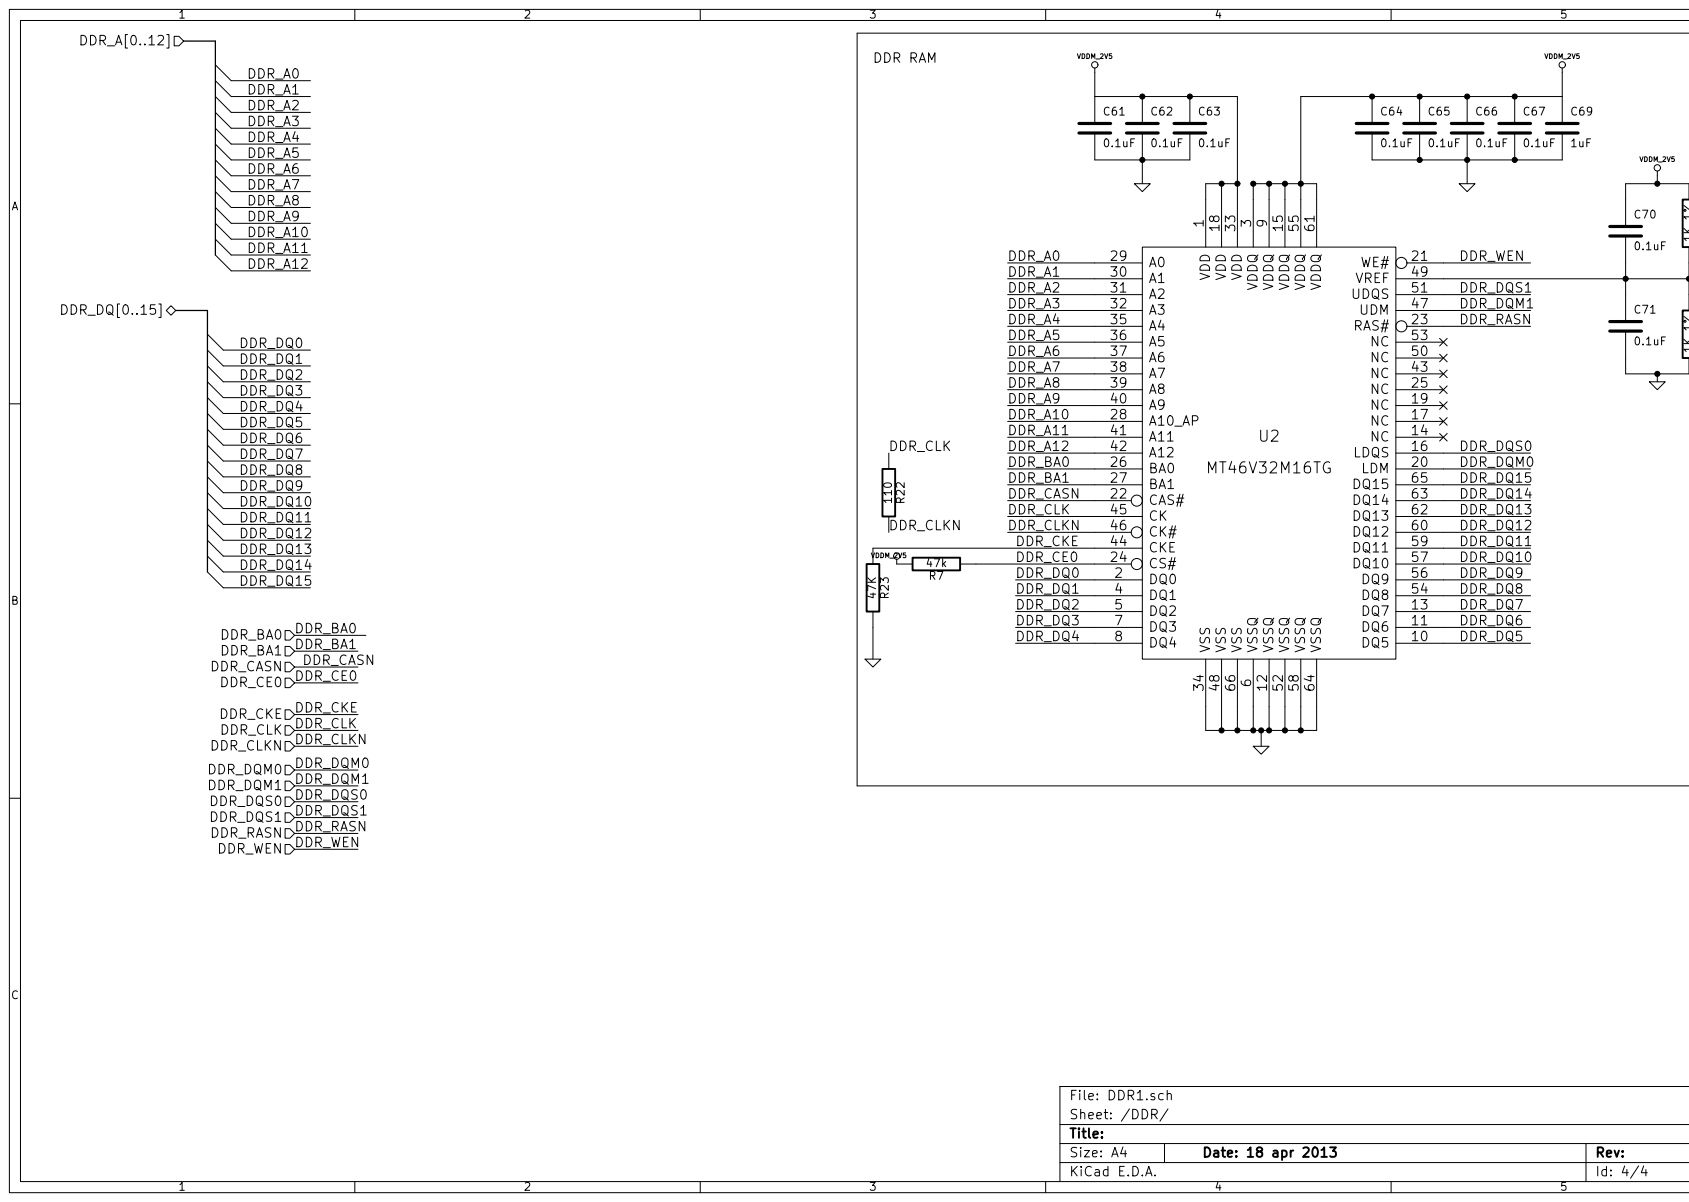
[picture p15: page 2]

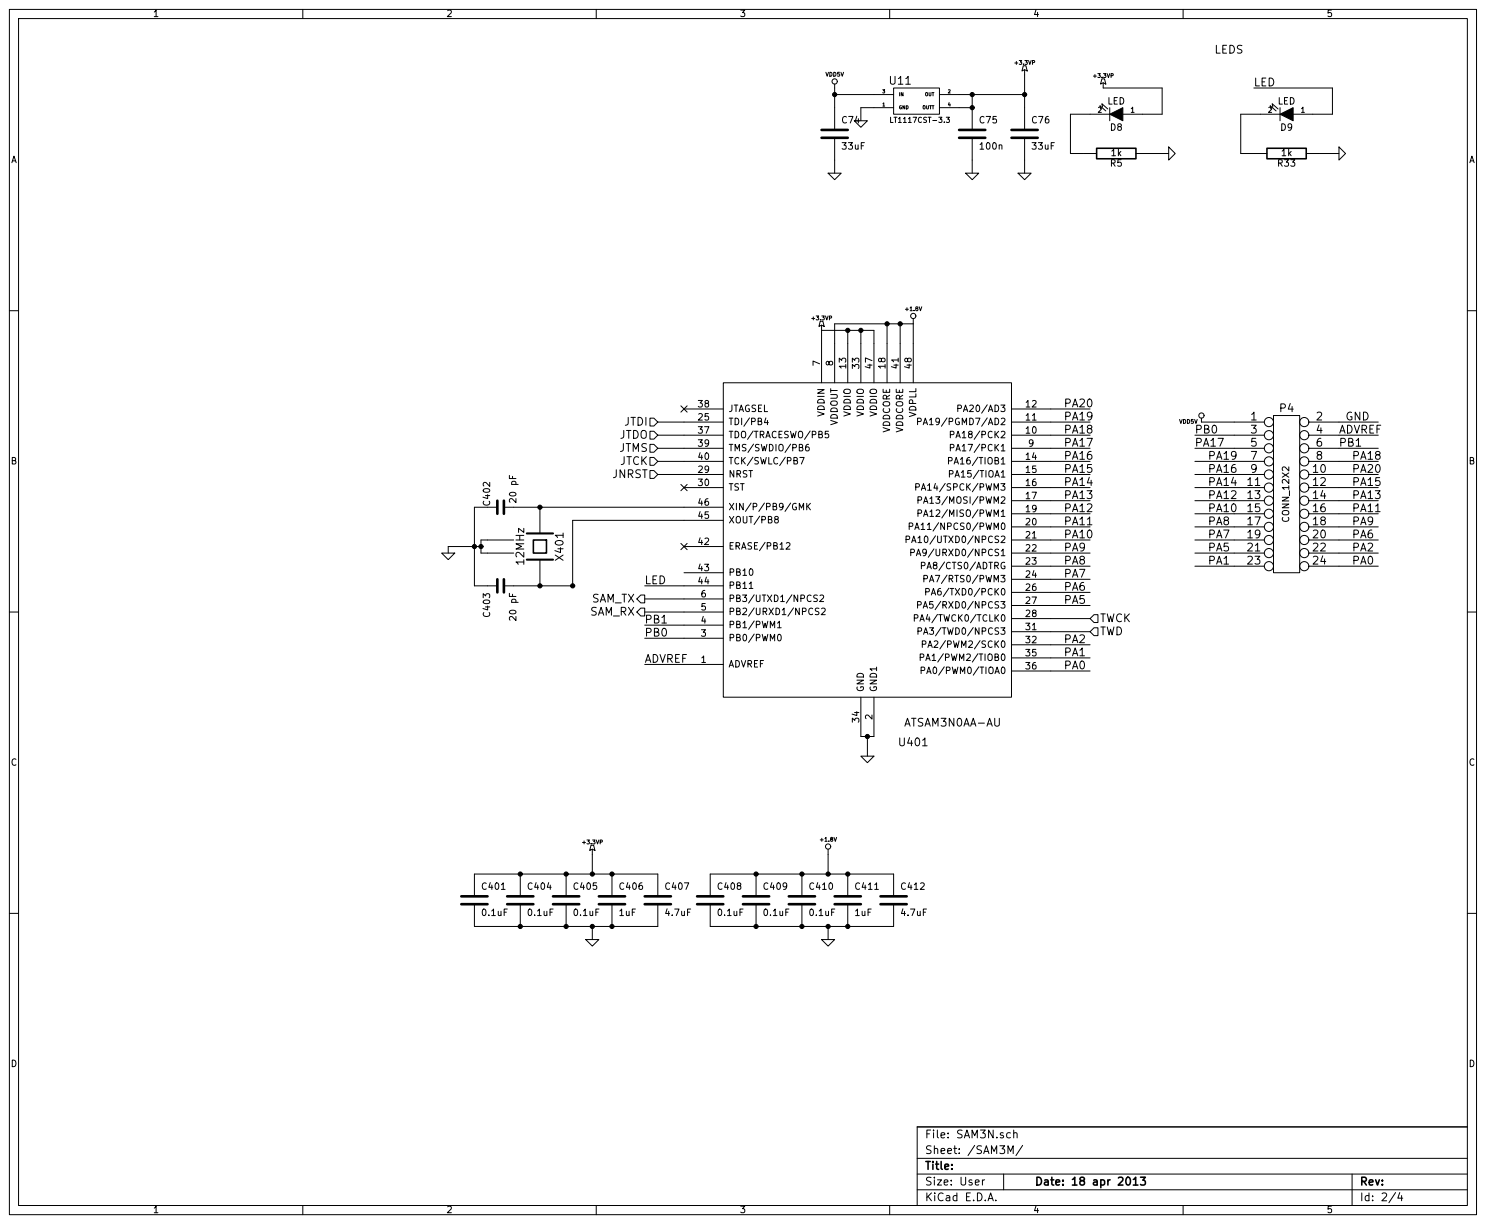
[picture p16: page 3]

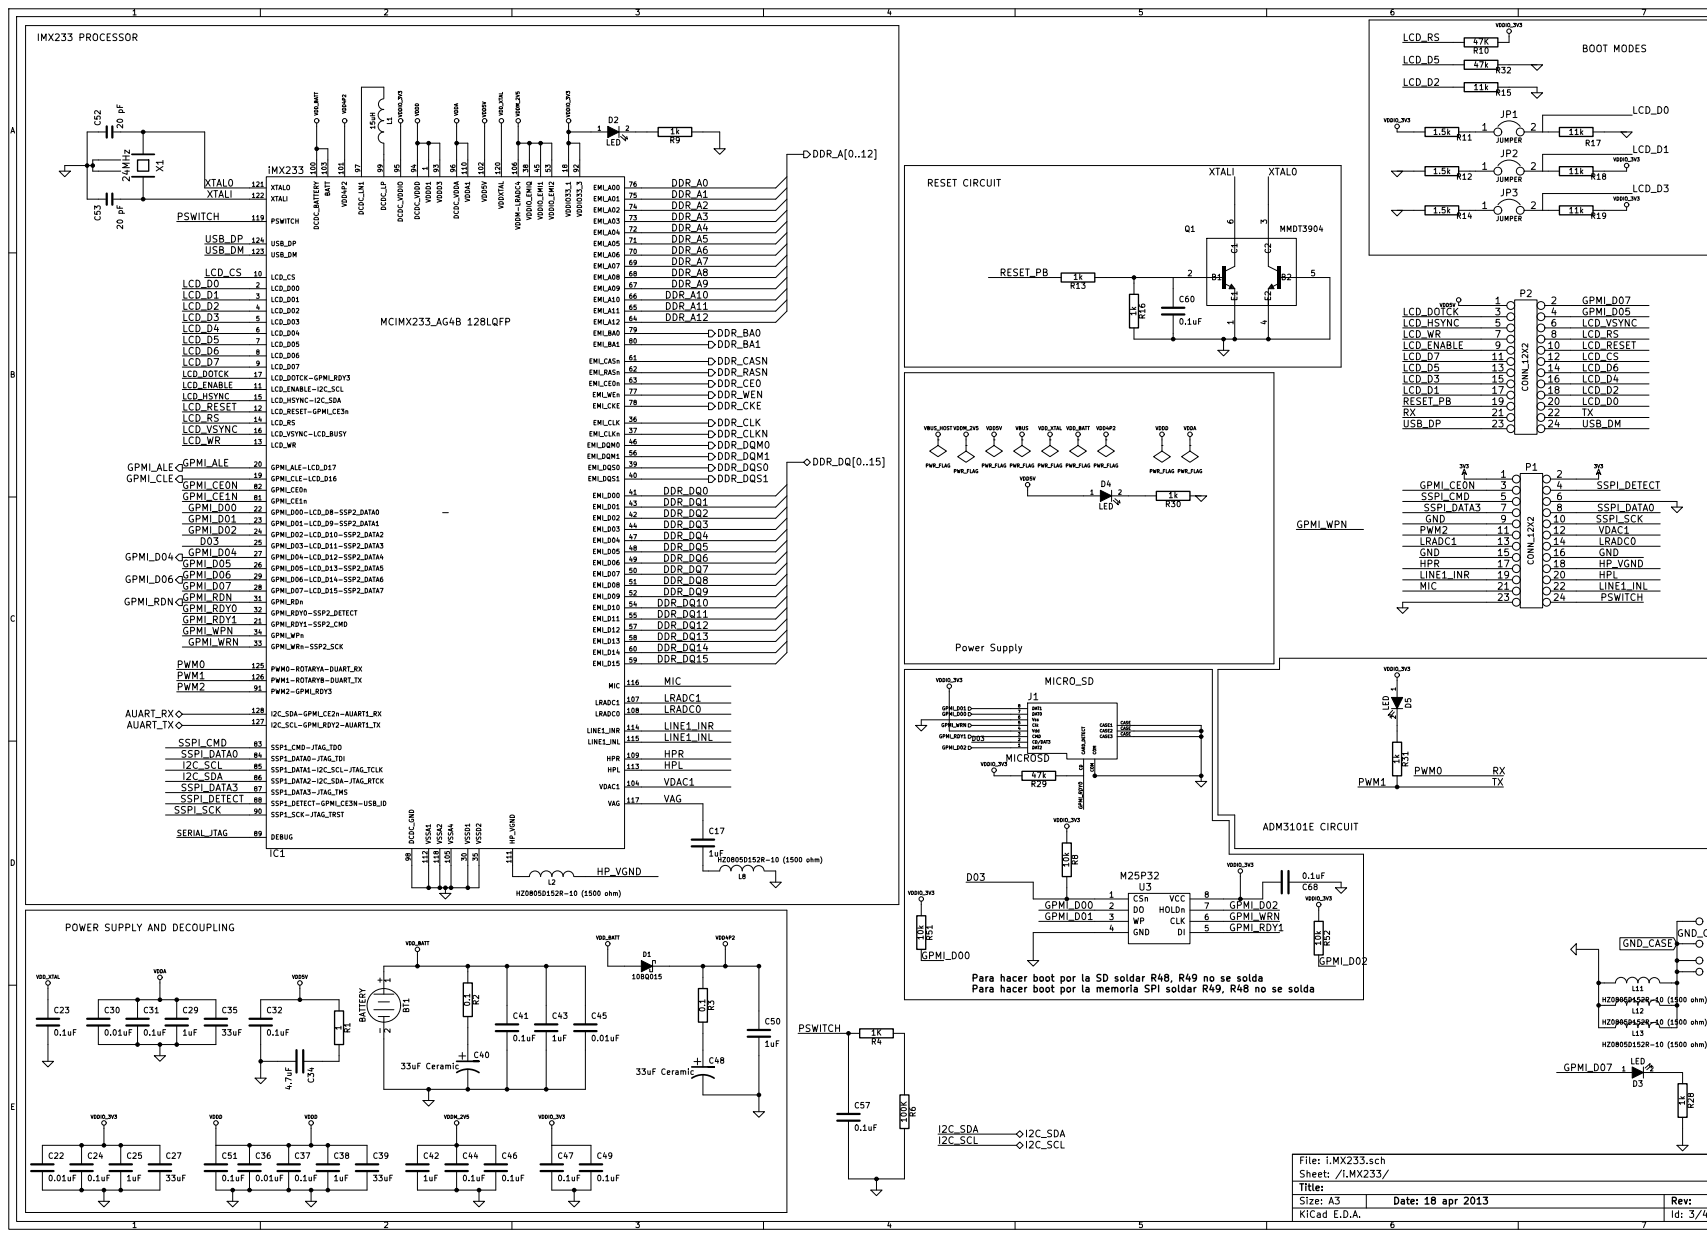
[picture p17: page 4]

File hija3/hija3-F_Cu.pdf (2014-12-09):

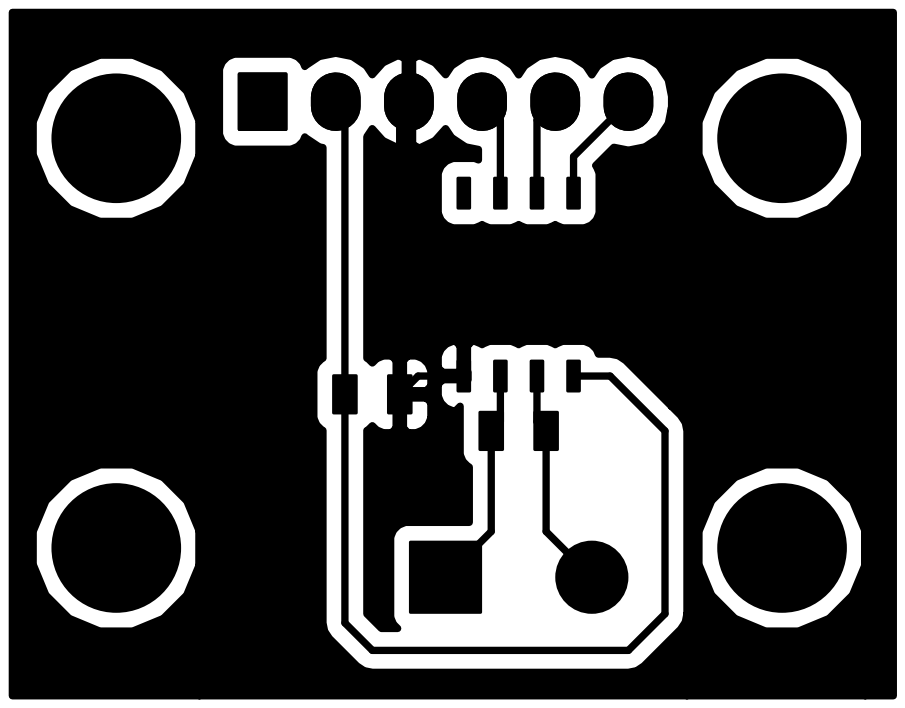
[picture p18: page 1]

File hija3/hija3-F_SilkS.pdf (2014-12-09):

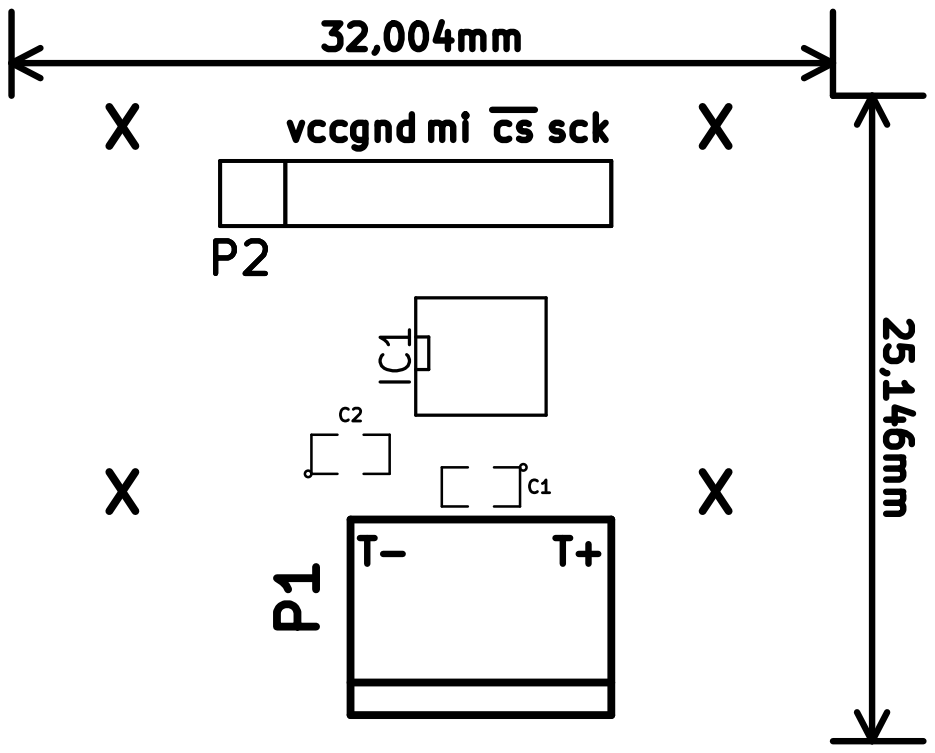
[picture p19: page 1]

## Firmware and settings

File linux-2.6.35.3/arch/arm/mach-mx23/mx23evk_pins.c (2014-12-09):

/*
 * Copyright (C) 2009-2010 Freescale Semiconductor, Inc. All Rights Reserved.
 *
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
 * You should have received a copy of the GNU General Public License along
 * with this program; if not, write to the Free Software Foundation, Inc.,
 * 51 Franklin Street, Fifth Floor, Boston, MA 02110-1301 USA.
 */

#include <linux/kernel.h>
#include <linux/init.h>
#include <linux/platform_device.h>
#include <linux/irq.h>
#include <linux/gpio.h>
#include <linux/delay.h>

#include <mach/pinctrl.h>
#include <linux/leds.h>

#include "mx23_pins.h"

static struct pin_desc mx23evk_fixed_pins[] = {
	{
	 .name = "DUART.RX",
	 .id = PINID_PWM0,
	 .fun = PIN_FUN3,
	 },
	{
	 .name = "DUART.TX",
	 .id = PINID_PWM1,
	 .fun = PIN_FUN3,
	 }, 
	{
	 .name = "AUART1.RX",
	 .id = PINID_I2C_SDA,
	 .fun = PIN_FUN3,
	 .strength = PAD_4MA,
	 .voltage = PAD_3_3V,
//	 .drive	= 1,
	 },
	{
	 .name = "AUART1.TX",
	 .id = PINID_I2C_SCL,
	 .fun = PIN_FUN3,
	 .strength = PAD_4MA,
	 .voltage = PAD_3_3V,
//	 .drive	= 1,
	 },
/*#if defined(CONFIG_I2C_MXS) || \
	defined(CONFIG_I2C_MXS_MODULE)
	{
	 .name = "I2C_SCL",
	 .fun = PIN_FUN1,
	 .strength = PAD_4MA,
	 .voltage = PAD_3_3V,
	 .drive	= 1,
	 },
	{
	 .name = "I2C_SDA",
	 .id = PINID_I2C_SDA,
	 .fun = PIN_FUN1,
	 .strength = PAD_4MA,
	 .voltage = PAD_3_3V,
	 .drive	= 1,
	 },
#endif
*/
#if defined(CONFIG_FB_MXS) || defined(CONFIG_FB_MXS_MODULE)
	{
	 .name  = "LCD_D00",
	 .id	= PINID_LCD_D00,
	 .fun	= PIN_FUN1,
	 .strength = PAD_8MA,
	 .voltage	= PAD_3_3V,
	 .drive	= 1,
	 },
	{
	 .name  = "LCD_D01",
	 .id	= PINID_LCD_D01,
	 .fun	= PIN_FUN1,
	 .strength = PAD_8MA,
	 .voltage	= PAD_3_3V,
	 .drive	= 1,
	 },
	{
	 .name  = "LCD_D02",
	 .id	= PINID_LCD_D02,
	 .fun	= PIN_FUN1,
	 .strength = PAD_8MA,
	 .voltage	= PAD_3_3V,
	 .drive	= 1,
	 },
	{
	 .name  = "LCD_D03",
	 .id	= PINID_LCD_D03,
	 .fun	= PIN_FUN1,
	 .strength = PAD_8MA,
	 .voltage	= PAD_3_3V,
	 .drive	= 1,
	 },
	{
	 .name  = "LCD_D04",
	 .id	= PINID_LCD_D04,
	 .fun	= PIN_FUN1,
	 .strength = PAD_8MA,
	 .voltage	= PAD_3_3V,
	 .drive	= 1,
	 },
	{
	 .name  = "LCD_D05",
	 .id	= PINID_LCD_D05,
	 .fun	= PIN_FUN1,
	 .strength = PAD_8MA,
	 .voltage	= PAD_3_3V,
	 .drive	= 1,
	 },
	{
	 .name  = "LCD_D06",
	 .id	= PINID_LCD_D06,
	 .fun	= PIN_FUN1,
	 .strength = PAD_8MA,
	 .voltage	= PAD_3_3V,
	 .drive	= 1,
	 },
	{
	 .name  = "LCD_D07",
	 .id	= PINID_LCD_D07,
	 .fun	= PIN_FUN1,
	 .strength = PAD_8MA,
	 .voltage	= PAD_3_3V,
	 .drive	= 1,
	 },
	{
	 .name = "LCD_RESET",
	 .id = PINID_LCD_RESET,
	 .fun = PIN_FUN1,
	 .strength = PAD_8MA,
	 .voltage = PAD_3_3V,
	 .drive	= 1,
	 },
/*	{
	 .name = "LCD_VSYNC",
	 .id   = PINID_LCD_VSYNC,
	 .fun  = PIN_FUN1,
	 .strength = PAD_8MA,
	 .voltage = PAD_3_3V,
	 .drive	= 1,
	 },
	{
	 .name = "LCD_HSYNC",
	 .id = PINID_LCD_HSYNC,
	 .fun = PIN_FUN1,
	 .strength = PAD_8MA,
	 .voltage = PAD_3_3V,
	 .drive	= 1,
	 },
	{
	 .name = "LCD_ENABLE",
	 .id = PINID_LCD_ENABLE,
	 .fun = PIN_FUN1,
	 .strength = PAD_8MA,
	 .voltage = PAD_3_3V,
	 .drive	= 1,
	 },mx23evk_spi_pins
	{
	 .name = "LCD_DOTCLK",
	 .id = PINID_LCD_DOTCK,
	 .fun = PIN_FUN1,
	 .strength = PAD_8MA,
	 .voltage = PAD_3_3V,
	 .drive	= 1,
	 },
	{
	 .name = "LCD_BACKLIGHT",
	 .id = PINID_PWM2,
	 .fun = PIN_FUN1,
	 .strength = PAD_8MA,
	 .voltage = PAD_3_3V,
	 .drive	= 1,
	 },
*/
	{
	 .name = "LCD_RS",
	 .id = PINID_LCD_RS,
	 .fun = PIN_FUN1,
	 .strength = PAD_8MA,
	 .voltage = PAD_3_3V,
	 .drive	= 1,
	 },
	{
	 .name = "LCD_CS",
	 .id = PINID_LCD_CS,
	 .fun = PIN_FUN1,
	 .strength = PAD_8MA,
	 .voltage = PAD_3_3V,
	 .drive	= 1,
	 },
	{
	 .name = "LCD_WR",
	 .id = PINID_LCD_WR,
	 .fun = PIN_FUN1,
	 .strength = PAD_8MA,
	 .voltage = PAD_3_3V,
	 .drive	= 1,
	 },
	{
	 .name = "LCD_ENABLE",
	 .id = PINID_LCD_ENABLE,
	 .fun = PIN_FUN1,
	 .strength = PAD_8MA,
	 .voltage = PAD_3_3V,
	 .drive	= 1,
	 },
#endif

};

#if defined(CONFIG_MMC_MXS) || defined(CONFIG_MMC_MXS_MODULE)
static struct pin_desc mx23evk_mmc_pins[] = {
	/* Configurations of SSP2 SD/MMC port pins */
	{
	 .name = "SSP2_DATA0",
	 .id = PINID_SSP2_DATA0,
	 .fun = PIN_FUN3,
	 .strength = PAD_8MA,
	 .voltage = PAD_3_3V,
	 .pullup = 1,
	 .drive = 1,
	 .pull = 1,
	 },
	{
	 .name = "SSP2_DATA1",
	 .id = PINID_SSP2_DATA1,
	 .fun = PIN_FUN3,
	 .strength = PAD_8MA,
	 .voltage = PAD_3_3V,
	 .pullup = 1,
	 .drive = 1,
	 .pull = 1,
	 },
	{
	 .name = "SSP2_DATA2",
	 .id = PINID_SSP2_DATA2,
	 .fun = PIN_FUN3,
	 .strength = PAD_8MA,
	 .voltage = PAD_3_3V,
	 .pullup = 1,
	 .drive = 1,
	 .pull = 1,
	 },
	{
	 .name = "SSP2_DATA3",
	 .id = PINID_SSP2_DATA3,
	 .fun = PIN_FUN3,
	 .strength = PAD_8MA,
	 .voltage = PAD_3_3V,
	 .pullup = 1,
	 .drive = 1,
	 .pull = 1,
	 },
	{
	 .name = "SSP2_CMD",
	 .id = PINID_SSP2_CMD,
	 .fun = PIN_FUN3,
	 .strength = PAD_8MA,
	 .voltage = PAD_3_3V,
	 .pullup = 1,
	 .drive = 1,
	 .pull = 1,
	 },
	{
	 .name = "SSP2_DETECT",
	 .id = PINID_SSP2_DETECT,
	 .fun = PIN_FUN3,
	 .strength = PAD_8MA,
	 .voltage = PAD_3_3V,
	 .pullup = 0,
	 .drive = 1,
	 .pull = 0,
	 },
	{
	 .name = "SSP2_SCK",
	 .id = PINID_SSP2_SCK,
	 .fun = PIN_FUN3,
	 .strength = PAD_8MA,
	 .voltage = PAD_3_3V,
	 .pullup = 0,
	 .drive = 1,
	 .pull = 0,
	 },
//asi estaba antes
/*	{
	 .name = "SSP1_SCK",
	 .id = PINID_SSP1_SCK,
	 .fun = PIN_FUN1,
	 .strength = PAD_8MA,
	 .voltage = PAD_3_3V,
	 .pullup = 0,
	 .drive = 1,
	 .pull = 0,
	 },*/
};
#endif

#if defined(CONFIG_SPI_MXS) || defined(CONFIG_SPI_MXS_MODULE)
static struct pin_desc mx23evk_spi_pins[] = {
	{
	 .name	= "SSP1_DATA0",
	 .id	= PINID_SSP1_DATA0,
	 .fun	= PIN_FUN1,
	 .strength	= PAD_4MA,
	 .voltage	= PAD_3_3V,
	 .drive 	= 1,
	 },
	{
	 .name	= "SSP1_DATA3",
	 .id	= PINID_SSP1_DATA3,
	 .fun	= PIN_FUN1,
	 .strength	= PAD_4MA,
	 .voltage	= PAD_3_3V,
	 .drive 	= 1,
	 },
	{
	 .name	= "SSP1_CMD",
	 .id	= PINID_SSP1_CMD,
	 .fun	= PIN_FUN1,
	 .strength	= PAD_4MA,
	 .voltage	= PAD_3_3V,
	 .drive 	= 1,
	 },
	{
	 .name	= "SSP1_SCK",
	 .id	= PINID_SSP1_SCK,
	 .fun	= PIN_FUN1,
	 .strength	= PAD_8MA,
	 .voltage	= PAD_3_3V,
	 .drive 	= 1,
	 },
};
#endif


static void mxs_request_pins(struct pin_desc *pins, int nr)
{
	int i;
	struct pin_desc *pin;

	/* configure the pins */
	for (i = 0; i < nr; i++) {
		pin = &pins[i];
		if (pin->fun == PIN_GPIO)
			gpio_request(MXS_PIN_TO_GPIO(pin->id), pin->name);
		else
			mxs_request_pin(pin->id, pin->fun, pin->name);
		if (pin->drive) {
			mxs_set_strength(pin->id, pin->strength, pin->name);
			mxs_set_voltage(pin->id, pin->voltage, pin->name);
		}
		if (pin->pull)
			mxs_set_pullup(pin->id, pin->pullup, pin->name);
		if (pin->fun == PIN_GPIO) {
			if (pin->output)
				gpio_direction_output(MXS_PIN_TO_GPIO(pin->id),
						      pin->data);
			else
				gpio_direction_input(MXS_PIN_TO_GPIO(pin->id));
		}
	}
}

static void mxs_release_pins(struct pin_desc *pins, int nr)
{
	int i;
	struct pin_desc *pin;

	/* release the pins */
	for (i = 0; i < nr; i++) {
		pin = &pins[i];
		if (pin->fun == PIN_GPIO)
			gpio_free(MXS_PIN_TO_GPIO(pin->id));
		else
			mxs_release_pin(pin->id, pin->name);
	}
}
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

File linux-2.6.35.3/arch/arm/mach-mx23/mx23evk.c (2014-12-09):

/*
 * Copyright (C) 2009-2010 Freescale Semiconductor, Inc. All Rights Reserved.
 *
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
 * You should have received a copy of the GNU General Public License along
 * with this program; if not, write to the Free Software Foundation, Inc.,
 * 51 Franklin Street, Fifth Floor, Boston, MA 02110-1301 USA.
 */

#include <linux/kernel.h>
#include <linux/init.h>
#include <linux/io.h>
#include <linux/clk.h>
#include <linux/platform_device.h>
#include <linux/i2c.h>
#include <linux/i2c/at24.h>
#include <linux/spi/spi.h>
//#include <linux/spi/spi_gpio.h>
#include <linux/spi/ads7846.h>
#include <linux/regulator/machine.h>
#include <linux/regulator/fixed.h>

#include <asm/setup.h>
#include <asm/mach-types.h>
#include <asm/mach/arch.h>

#include <mach/hardware.h>
#include <mach/device.h>
#include <mach/pinctrl.h>
#include <mach/regs-ocotp.h>


#include "device.h"
#include "mx23evk.h"
#include "mx23_pins.h"

// #define AT24C256
//#define TS_PENIRQ_GPIO PINID_SSP1_DATA1

static struct at24_platform_data at24cXXX_platdata = {
    .byte_len    = SZ_8K / 8,
    .page_size    = 128,
#ifdef AT24C256    
    .flags = AT24_FLAG_ADDR16,
#else
    .flags = AT24_FLAG_TAKE8ADDR,
#endif    
};

static struct i2c_board_info __initdata at24cXXX_i2c_device = {
#ifdef AT24C256 	
	I2C_BOARD_INFO("at24c256", 0x50),
#else
	I2C_BOARD_INFO("at24c08", 0x50),
#endif
	.platform_data = (void *)&at24cXXX_platdata,
};

static void i2c_device_init(void)
{
	i2c_register_board_info(0, &at24cXXX_i2c_device, 1);
}

#if defined(CONFIG_SPI_MXS) || defined(CONFIG_SPI_MXS_MODULE)
static struct mxs_spi_platform_data ssp1_data = {
	.hw_pin_init = mxs_spi_enc_pin_init,
	.hw_pin_release = mxs_spi_enc_pin_release,
	.clk = "ssp.0",
};
#endif

#if defined(CONFIG_TOUCHSCREEN_ADS7846)
//#define TS_PENIRQ_GPIO PINID_PWM2
#define TS_PENIRQ_GPIO PINID_GPMI_D05




struct platform_device sk_spi_gpio_device = {
       .name    = "mxs-spi",
       .id      = 1,
       .dev     = {
                .platform_data = &ssp1_data,
       },
};

static int ads7846_dev_init(void)
{ 
        if (gpio_request(MXS_PIN_TO_GPIO(TS_PENIRQ_GPIO), "ADS7846 pendown") < 0)
                printk(KERN_ERR "can't get ads7846 pen down GPIO\n");

        gpio_direction_input(MXS_PIN_TO_GPIO(TS_PENIRQ_GPIO));
        set_irq_type(gpio_to_irq(MXS_PIN_TO_GPIO(TS_PENIRQ_GPIO)), IRQ_TYPE_EDGE_FALLING);

        return gpio_to_irq(MXS_PIN_TO_GPIO(TS_PENIRQ_GPIO));
}

static int ads7843_pendown_state(void)
{
        return !gpio_get_value(MXS_PIN_TO_GPIO(TS_PENIRQ_GPIO));      /* Touchscreen PENIRQ */
}

static struct ads7846_platform_data ads_info = {
        .model                  = 7846,
        .x_min                  = 150,
        .x_max                  = 3830,
        .y_min                  = 190,
        .y_max                  = 3830,
        .vref_delay_usecs       = 0,//100
		.penirq_recheck_delay_usecs = 200,//Nuevo
		.pressure_min			= 128,	
		.pressure_max			= 1024,
        .debounce_max           = 15,//10
        .debounce_tol           = 5,//3
        .debounce_rep           = 1,//1
		.x_plate_ohms           = 250,
        .y_plate_ohms           = 450,
		.swap_xy 				= 1,
        .get_pendown_state      = ads7843_pendown_state,
//		.wakeup 				= 1,
//	    .keep_vref_on			=1,
};
#endif

static struct spi_board_info spi_board_info[] __initdata = {
#if defined(CONFIG_TOUCHSCREEN_ADS7846)
//       [0]= {       /* Touchscreen support */
//                .modalias       = "ads7846",
//                .max_speed_hz   = 100 * 1000,
//                .bus_num        = 1,
//                .controller_data = (void *) MXS_PIN_TO_GPIO(PINID_SSP1_DATA3),
//                .platform_data  = &ads_info,
//        },
//#endif
//#if defined(CONFIG_KS8851) || defined(CONFIG_KS8851_MODULE) 
	[0] = {
		.modalias       = "ads7846",
		.max_speed_hz   = 120000,
 		.bus_num	= 1,
 		.chip_select    = 0,
		.irq            = PINID_SSP1_DATA1,
 		.platform_data  = &ads_info,
 	},
 #endif

 #if defined(CONFIG_SPI_SPIDEV)
	[0] = {
		.modalias 	= "spidev",
 
		.max_speed_hz 	= 500000,//hay que revisar para cuadrar con la velocidad del max31855 < 5MHz
		.bus_num 	= 1,
		.chip_select 	= 0,
		.irq		= PINID_SSP1_DATA0,
		.platform_data 	= &ssp1_data,
	},
 #endif
};

static void spi_device_init(void)
{
#if defined(CONFIG_TOUCHSCREEN_ADS7846)
        platform_device_register(&sk_spi_gpio_device);
        spi_board_info[0].irq = ads7846_dev_init();
#endif
	//spi_board_info[0].irq = gpio_to_irq(MXS_PIN_TO_GPIO(PINID_SSP1_DATA1));
	spi_register_board_info(spi_board_info, ARRAY_SIZE(spi_board_info));
}

static void __init fixup_board(struct machine_desc *desc, struct tag *tags,
			       char **cmdline, struct meminfo *mi)
{
	mx23_set_input_clk(24000000, 24000000, 32000, 50000000);
}

#if defined(CONFIG_SND_MXS_SOC_ADC) || defined(CONFIG_SND_MXS_SOC_ADC_MODULE)
static void __init mx23evk_init_adc(void)
{
	struct platform_device *pdev;
	pdev = mxs_get_device("mxs-adc", 0);
	if (pdev == NULL)
		return;
	mxs_add_device(pdev, 3);
}
#else
static void __init mx23evk_init_adc(void)
{

}
#endif

#define REGS_OCOTP_BASE	IO_ADDRESS(OCOTP_PHYS_ADDR)
int get_evk_board_version()
{
	int boardid;
	boardid = __raw_readl(REGS_OCOTP_BASE + HW_OCOTP_CUSTCAP);
	boardid &= 0x30000000;
	boardid = boardid >> 28;

	return boardid;
}
EXPORT_SYMBOL_GPL(get_evk_board_version);

static void __init mx23evk_device_init(void)
{
	/* Add mx23evk special code */
	i2c_device_init();
	spi_device_init();
	mx23evk_init_adc();
}


static void __init mx23evk_init_machine(void)
{
	mx23_pinctrl_init();

	/* Init iram allocate */
#ifdef CONFIG_VECTORS_PHY_ADDR
	/* reserve the first page for irq vectors table*/
	iram_init(MX23_OCRAM_PHBASE + PAGE_SIZE, MX23_OCRAM_SIZE - PAGE_SIZE);
#else
	iram_init(MX23_OCRAM_PHBASE, MX23_OCRAM_SIZE);
#endif

	mx23_gpio_init();
	mx23evk_pins_init();
	mx23_device_init();
	mx23evk_device_init();
}

MACHINE_START(MX23EVK, "Freescale MX23EVK board")
	.phys_io	= 0x80000000,
	.io_pg_offst	= ((0xf0000000) >> 18) & 0xfffc,
	.boot_params	= 0x40000100,
	.fixup		= fixup_board,
	.map_io		= mx23_map_io,
	.init_irq	= mx23_irq_init,
	.init_machine	= mx23evk_init_machine,
	.timer		= &mx23_timer.timer,
MACHINE_END

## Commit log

2014-12-09 subo hija y paginas
    [hija3.kicad_pcb, hija3.sch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]
2014-12-09 subo configuracion SPI
    [MOD-TC.production.obj]
2014-12-09 kernel y demas archivo de configuracion
    [ALSA-Configuration.txt, config.txt, configfs.txt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]
2014-12-10 Create README.md
    agrego una aclaracion de los archivos
2014-12-10 Create README.md
    se explica que archivos se usaron al final

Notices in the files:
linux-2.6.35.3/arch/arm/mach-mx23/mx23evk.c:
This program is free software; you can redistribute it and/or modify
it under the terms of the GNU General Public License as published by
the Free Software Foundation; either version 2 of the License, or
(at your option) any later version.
